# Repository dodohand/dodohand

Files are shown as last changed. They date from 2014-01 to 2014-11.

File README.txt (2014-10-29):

Please see the GeekHack thread on this topic for details.

http://geekhack.org/index.php?topic=41422.0

This project is built around the Teensy 2.0 and is currently using
debug tools from PJRC. Please find the hid_listen tool from PJRC
in order to receive the debug messages from the test DodoHand 
firmware.

At attempt at some coherent notes:

A Brief History

The DataHand keyboard is a design that I have come to rely heavily
upon and do not want to be without. It allows me to type pain-free
for hours at a time, day after day. DataHand Systems has been out
of production for some 10 years now, and their website has even
recently been taken down so I feel left to my own devices to ensure
a long-term future of pain-free typing. This has spawned the DodoHand
project - an attempt to resurrect the now-extinct DataHand.

So you want to create a DodoHand

Current status: The finger switch design is usable. The thumb switch
mechanism designs are complete in their first version, but untested.
A thumb PCB has been designed and ordered. A case has been designed by
Turbinia, but has never been built. There are provisions in hardware
for supporting an EasyPoint or another joystick but these have not
been implemented in software.

Note:

At this point, only the finger switches are tested in any way, and
the rest of the document mainly refers to that portion of the project.

The first step is to get all the parts headed your way. There is 
a BOM.ods (Bill of Materials) in the documentation folder which 
contains a list of the parts needed. That should be your guide.

- Electronics:

There are part numbers and links to Digikey which should make
it easier to get the electronics order placed. 

- 3D-printed parts:

In the 3D_models directory the files plf.scad and show_prf.scad 
should be opened with a recent version of OpenSCAD, compiled, and 
exported as .STL files. These can then be uploaded to Shapeways 
and printed in the "Black, Strong and Flexible" material. Please 
note that there are some fairly tight tolerances and that the 
design requires a bit of flexibility in the printed models in 
order to retain the magnets and center button clips, so don't 
try to print them in an inflexible, or fragile material, or one
with less fidelity than the SLS Nylon "Black, Strong and Flexible".

- PCB:

In the sch_and_pcb folder open up kicad_fingers.brd with a recent
build of KiCAD (I have been working with a build from sources
downloaded in November, 2013) and plot the Gerber files. Verify 
that the drill file matches up with the other files using gerbview
or another Gerber file viewer, then send to a suitable PCB fab
operation like OSH Park, pcbwing, etc. Note that OSH Park will
silently drop overlapping holes so the double-sided TRRS connector
footprint will not be manufactured exactly correctly, but is very
usable anyhow.

Note that you're likely going to need to edit the KiCAD library 
settings in order to point KiCAD at the appropriate library files
in the component_lib directory.

- Metal "clips" which serve as a magnetic attractor

These you'll need to fabricate on your own until/unless I (or you!) 
can find a shop to make them. There is a drawing: tooling/clip_bending_jig.dxf
which I used to create a bending jig. LibreCAD was used to create 
this drawing (turn various layers on/off to help see what's going on).
I substituted 1mm pins for all positions since that is what I was 
able to find from McMaster-Carr, and have been satisfied with the 
results. I used 7075 aluminum IIRC for the body of the jig. Be 
certain to order several drill bits of these small sizes - they're 
very fragile. Also, find a drill press or mill - you aren't likely 
to be successful trying to drill these holes by hand. I think that
0.045"x0.015" strips of mild steel will generate about the right 
force. Some experimentation will likely be needed to get that perfect.
This material can be sourced as a roll of 0.015" shim stock. Please be 
careful when releasing the coiled shim-stock from the strap that
holds it. It will jump out and try to cut your face off if you give
it half a chance to do so.

I am working towards getting a manufacturer lined up for the metal
clips. The first step is a clear mechanical drawing and I hope that
tooling/clip_1_mech.dxf fits that description.

Assembly

The only challenging part of assembly is fitting the 3D-printed parts
together. The Shapeways process has varied enough that some batches
fall right together without much work while others require quite a 
bit of time with a hobby knife, pick, and pin vise. These tools are
needed to re-open the passages for the infrared LED and phototransistor
leads, remove partially sintered material that was not cleaned away
by shapeways, and trim away excess material when their process is 
running on the extra-material end of the spectrum. You are likely
to spend between 2 and 15 minutes on each finger, depending upon 
your luck with Shapeways. Be thorough with the pick in removing
partially sintered material, or each time you insert a part, it
won't go well and you'll end up picking out another little batch
of dust to clear up the void that should have been there.

You should consider ordering a solder-paste stencil for each side
of the PCB. I did the 160 0-Ohm jumpers by-hand, meting out little
dabs of paste onto each pad. That went fine, but I would really
have liked to be able to just squeege across and get on to dropping
those little buggers onto their homes. If you do this, let me know
how it goes!

Don't be afraid of SMD soldering if you haven't done it before.
Particularly with a hot-air wand, it is magically easy. Just a dab
of paste on each pad, drop the part into position, warm it up, and 
when the solder flows the part is pulled into the right spot by
surface tension in the solder. It is just so cool!

Tools used for Assembly:

Here is the list of tools that I recall using so-far in this process:

- a file for cleaning up the little tabs left on the edge of the PCB
  which inevitably get placed right in front of the TRRS connector 
  which is the one spot that they cannot be tolerated.
- no-clean flux
- no-clean wire solder (leaded)
- no-clean solder paste (leaded) (in a syringe)
- no-clean de-soldering braid
- temperature controlled iron - small chisel tip
- hot-air re-work wand
- flush-cut lead snips
- various curved and straight tweezers
- bench shear for cutting metal clips
- dial calipers for measuring and setting metal clip dimensions
- combination square for controlling cuts on bench shear
- diagonal cutters for trimming metal clips to length.
- digital multimeter for testing solder joints
- dental pick
- hobby knife
- Mill for accurately placing holes in bending jig
- tiny drill bits for holes for 1mm pins in bending jig
- pin vise and assorted pin vise drill bits for opening IR lead passages

Software Tools used in project:
- OpenSCAD (build from recent sources) [3D models of switch mechanicals]
- KiCAD (build from recent sources - November, 2013 or later) [schematic, PCB]
- LibreCAD (version 1.0.1) [2D mechanical drawings]
- LibreOffice [Bill of Materials]
- Blender [case design, .stl file validation]
- Inkscape [documentation, logo]
- avr-gcc [compiling software for ATMega32U4 micro]
- GNU make [controlling build process]
- teensy_loader_cli [flashing ATMega32U4 through USB via teensy bootloader]
- simavr (optional) [extreme AVR debugging]
- git [distributed version control]

Programming the keyboard

Yeah, about that... I don't have the actual keyboard firmware written
quite yet. src/led_test.c scans the matrix of the right-hand side of
the keyboard via I2C and recognizes switch presses, and also scans the
left-hand side, but that is as far as I have currently taken it. Soon...

In any case, the Teensy 2.0 comes with a nice bootloader, and the
tactile switch SW1 is hooked to the teensy reset switch which starts
the bootloader. If you get the paths set correctly in Makefile for 
your system, and type make test_prog, the source will build and then
wait to recognize the Teensy bootloader - just press that reset at
that time and away you go.

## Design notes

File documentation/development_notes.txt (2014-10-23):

A place to capture some notes on development steps, strategies, etc.

1) How to verify that the 3D model matches the PCB layout?

So far, the best approach I've used is no take the drill file output
of the PCB design tool and translate it into a bunch of cylinders
in the 3D model. I imported the drill file into OpenOffice Calc,
converted inches to mm, copied the resulting data into Emacs along
with a column that I created for drill diameters. I then created 
an emacs keyboard macro to create something like this for each drill
of interest (only the mounting holes, component leads:

translate([-24.89454,    9.23036, 0]) 
  cylinder(center=true, $fn=gfn, h=100, r= 0.762/2.0);

and add the whole set to the 3D model.

When this matches the 3D model, you can be certain that the PCB
will properly line up with the holes in the switch parts.

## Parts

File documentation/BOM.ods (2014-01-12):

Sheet: Bill of Materials
 |  |  |  |  |  |  |  |  |  |  |  |  |  | mm | mm | mm | inch
Part ID | Description | Supplier | Supplier PN | Manufacturer | Manufacturer PN | Price Each | Quantity | extended | Notes | More Notes | Even More Notes | Added notes | package | l | w | terminal | lead diameter
1 | U2 5v decoupling Cap | Digikey | 445-14795-1-ND (http://www.digikey.com/product-detail/en/C3216X7R1C475K085AB/445-14795-1-ND/3956461) | TDK | C3216X7R1C475K085AB (http://www.digikey.com/product-detail/en/C3216X7R1C475K085AB/445-14795-1-ND/3956461) | $0.28 | 1 | $0.28 |  |  |  |  | 1206 | 3.2 | 1.6 | 0.2
2 | U2 3.3v output cap | Digikey | 445-14795-1-ND (http://www.digikey.com/product-detail/en/C3216X7R1C475K085AB/445-14795-1-ND/3956461) | TDK | C3216X7R1C475K085AB (http://www.digikey.com/product-detail/en/C3216X7R1C475K085AB/445-14795-1-ND/3956461) | $0.28 | 1 | $0.28 |  |  |  |  | 1206 | 3.2 | 1.6 | 0.2
3 | Standard 0.1u decoupling cap | Digikey | 1276-2856-1-ND (http://www.digikey.com/product-detail/en/CL31F104ZBCNNNC/1276-2856-1-ND/3890942) | Samsung | CL31F104ZBCNNNC (http://www.digikey.com/product-detail/en/CL31F104ZBCNNNC/1276-2856-1-ND/3890942) | $0.14 | 3 | $0.42 |  |  |  |  | 1206 | 3.2 | 1.6
4 | 3mm blue LED | Digikey | 365-1201-ND (http://www.digikey.com/product-detail/en/OVLLB8C7/365-1201-ND/827137) | TT Elec / Optek | OVLLB8C7 (http://www.digikey.com/product-detail/en/OVLLB8C7/365-1201-ND/827137) | $0.32 | 2 | $0.64 | 5mm 300mcd @ 20mA / 3.4v | 1.3333333333 | 910 | 900 |  |  |  |  | 0.029
5 | 3mm green LED | Digikey | 365-1202-ND (http://www.digikey.com/product-detail/en/OVLLG8C7/365-1202-ND/827138) | TT Elec / Optek | OVLLG8C7 (http://www.digikey.com/product-detail/en/OVLLG8C7/365-1202-ND/827138) | $0.35 | 2 | $0.70 | 5mm 670mcd @ 20mA / 3.4v | 0.5970149254 | 2112.5 | 2.1k |  |  |  |  | 0.029
6 | 3mm yellow LED | Digikey | 365-1204-ND (http://www.digikey.com/product-detail/en/OVLLY8C7/365-1204-ND/827140) | TT Elec / Optek | OVLLY8C7 (http://www.digikey.com/product-detail/en/OVLLY8C7/365-1204-ND/827140) | $0.19 | 2 | $0.38 | 5mm 650mcd @ 20mA / 2.2v | 0.6153846154 | 3997.5 | 4k |  |  |  |  | 0.029
7 | 3mm red LED | Digikey | 365-1203-ND (http://www.digikey.com/product-detail/en/OVLLR8C7/365-1203-ND/827139) | TT Elec / Optek | OVLLR8C7 (http://www.digikey.com/product-detail/en/OVLLR8C7/365-1203-ND/827139) | $0.19 | 2 | $0.38 | 5mm 570mcd @ 20mA / 2.2v | 0.701754386 | 3497.5 | 3.5k |  |  |  |  | 0.029
8 | 8 position 0.100 pth header | Digikey | 609-3530-ND (http://www.digikey.com/product-detail/en/75869-132LF/609-3530-ND/1524248) | FCI | 75869-132LF (http://www.digikey.com/product-detail/en/75869-132LF/609-3530-ND/1524248) | $0.80 | 5 | $4.00
9 | TRRS Connector | Digikey | CP-43514-ND (http://www.digikey.com/product-detail/en/SJ-43514/CP-43514-ND/368146) | CUI Inc | SJ-43514 (http://www.digikey.com/product-detail/en/SJ-43514/CP-43514-ND/368146) | $1.31 | 2 | $2.62
10 | test point | Digikey | 1040K-ND (http://www.digikey.com/product-detail/en/1040/1040K-ND/315157) | Keystone Electronics | 1040 (http://www.digikey.com/product-detail/en/1040/1040K-ND/315157) | $0.18 | 22 | $3.96
11 | PNP transistor | Digikey | KSA1298YMTFCT-ND (http://www.digikey.com/product-detail/en/KSA1298YMTF/KSA1298YMTFCT-ND/3504462) | Fairchild | KSA1298YMTF (http://www.digikey.com/product-detail/en/KSA1298YMTF/KSA1298YMTFCT-ND/3504462) | $0.22 | 1 | $0.22
12 | U3 pullup resistor | Digikey | P200KFCT-ND (http://www.digikey.com/product-detail/en/ERJ-8ENF2003V/P200KFCT-ND/89947) | Panasonic | ERJ-8ENF2003V (http://www.digikey.com/product-detail/en/ERJ-8ENF2003V/P200KFCT-ND/89947) | $0.10 | 1 | $0.10 |  |  |  |  | 1206 | 3.2 | 1.6
13 | I2C pullup resistor | Digikey | P2.20KFCT-ND (http://www.digikey.com/product-detail/en/ERJ-8ENF2201V/P2.20KFCT-ND/1746562) | Panasonic | ERJ-8ENF2201V (http://www.digikey.com/product-detail/en/ERJ-8ENF2201V/P2.20KFCT-ND/1746562) | $0.10 | 4 | $0.40 |  |  |  |  | 1206 | 3.2 | 1.6
14 | Row Resistor | Digikey | P470FCT-ND (http://www.digikey.com/product-detail/en/ERJ-8ENF4700V/P470FCT-ND/1746601) | Panasonic | ERJ-8ENF4700V (http://www.digikey.com/product-detail/en/ERJ-8ENF4700V/P470FCT-ND/1746601) | $0.10 | 4 | $0.40 |  |  |  |  | 1206 | 3.2 | 1.6
15 | column resistor | Digikey | P2.49KFCT-ND (http://www.digikey.com/product-detail/en/ERJ-8ENF2491V/P2.49KFCT-ND/89732) | Panasonic | ERJ-8ENF2491V (http://www.digikey.com/product-detail/en/ERJ-8ENF2491V/P2.49KFCT-ND/89732) | $0.10 | 8 | $0.80 |  |  |  |  | 1206 | 3.2 | 1.6
16 | Blue LED bias resistor | Digikey | P910FCT-ND (http://www.digikey.com/product-detail/en/ERJ-8ENF9100V/P910FCT-ND/1746631) | Panasonic | ERJ-8ENF9100V (http://www.digikey.com/product-detail/en/ERJ-8ENF9100V/P910FCT-ND/1746631) | $0.10 | 2 | $0.20 | 900 Ohms ish |  |  |  | 1206 | 3.2 | 1.6
17 | Green LED bias resistor | Digikey | P2.10KFCT-ND (http://www.digikey.com/product-detail/en/ERJ-8ENF2101V/P2.10KFCT-ND/89717) | Panasonic | ERJ-8ENF2101V (http://www.digikey.com/product-detail/en/ERJ-8ENF2101V/P2.10KFCT-ND/89717) | $0.10 | 2 | $0.20 | 2.1k ish |  |  |  | 1206 | 3.2 | 1.6
18 | Yellow LED bias resistor | Digikey | P4.02KFCT-ND (http://www.digikey.com/product-detail/en/ERJ-8ENF4021V/P4.02KFCT-ND/89767) | Panasonic | ERJ-8ENF4021V (http://www.digikey.com/product-detail/en/ERJ-8ENF4021V/P4.02KFCT-ND/89767) | $0.10 | 2 | $0.20 | 4k |  |  |  | 1206 | 3.2 | 1.6
19 | Red LED bias resistor | Digikey | P3.48KFCT-ND (http://www.digikey.com/product-detail/en/ERJ-8ENF3481V/P3.48KFCT-ND/89751) | Panasonic | ERJ-8ENF3481V (http://www.digikey.com/product-detail/en/ERJ-8ENF3481V/P3.48KFCT-ND/89751) | $0.10 | 2 | $0.20 | 3.5k |  |  |  | 1206 | 3.2 | 1.6
20 | EP SW eval resistor | Digikey | P4.99KFCT-ND (http://www.digikey.com/product-detail/en/ERJ-8ENF4991V/P4.99KFCT-ND/89788) | Panasonic | ERJ-8ENF4991V (http://www.digikey.com/product-detail/en/ERJ-8ENF4991V/P4.99KFCT-ND/89788) | $0.10 | 2 | $0.20 |  |  |  |  | 1206 | 3.2 | 1.6
21 | U4 pullup resistor | Digikey | P10.0KFCT-ND (http://www.digikey.com/product-detail/en/ERJ-8ENF1002V/P10.0KFCT-ND/89822) | Panasonic | ERJ-8ENF1002V (http://www.digikey.com/product-detail/en/ERJ-8ENF1002V/P10.0KFCT-ND/89822) | $0.10 | 1 | $0.10 |  |  |  |  | 1206 | 3.2 | 1.6
22 | reset switch | Digikey | CKN9120-ND (http://www.digikey.com/product-detail/en/PTS645VH58-2%20LFS/CKN9120-ND/1146783) | C&K Components | PTS645VH58-2 LFS | $0.24 | 1 | $0.24
23 | Teensy | pjrc | TEENSY_PINS | pjrc | TEENSY_PINS | $19.00 | 1 | $19.00
24 | 3.3v linear regulator | Digikey | AP7313-33SAG-7DICT-ND (http://www.digikey.com/product-detail/en/AP7313-33SAG-7/AP7313-33SAG-7DICT-ND/2270840) | Diodes, Inc | AP7313-33SAG-7 (http://www.digikey.com/product-detail/en/AP7313-33SAG-7/AP7313-33SAG-7DICT-ND/2270840) | $0.46 | 1 | $0.46
25 | I2C level shifter | Digikey | 568-4215-1-ND (http://www.digikey.com/product-detail/en/PCA9306D,118/568-4215-1-ND/1638362) | NXP | PCA9306 | $0.78 | 1 | $0.78
26 | I2C I/O expander | Digikey | PCA9655EDWR2GOSCT-ND (http://www.digikey.com/product-detail/en/PCA9655EDWR2G/PCA9655EDWR2GOSCT-ND/2683436) | ON Semi | PCA9655EDWR2G (http://www.digikey.com/product-detail/en/PCA9655EDWR2G/PCA9655EDWR2GOSCT-ND/2683436) | $1.43 | 1 | $1.43
27 | IRLED | Digikey | 160-1063-ND (http://www.digikey.com/product-detail/en/LTE-302/160-1063-ND/153264) | Lite-On | LTE-302 | $0.35 | 40 | $14.12
28 | IRPhotoTrans | Digikey | 1080-1163-ND (http://www.digikey.com/product-detail/en/PT908-7B-F/1080-1163-ND/2675654) | Everlight | PT908-7B-F | $0.33 | 40 | $13.08
38 | 0603 0-Ohm jumper | Digikey | 1276-3510-1-ND (http://www.digikey.com/product-detail/en/RC1608J000CS/1276-3510-1-ND/3903613) | Samsung | RC1608J000CS (http://www.digikey.com/product-detail/en/RC1608J000CS/1276-3510-1-ND/3903613) | $0.0027 | 160 | $0.4320 | Jumpers for connecting IR component leads to switch matrix.
34 | TRRS cable | MyCableMart | FS-4CT-01-MM | MyCableMart | FS-4CT-01-MM | $1.40 | 1 | $1.40
ribbon cable | 8-position 0.050 in spacing | Digikey | MD08R-5-ND (http://www.digikey.com/product-detail/en/HF365%2F08SF/MD08R-5-ND/2416331) | 3M | HF365/08SF (http://www.digikey.com/product-detail/en/HF365%2F08SF/MD08R-5-ND/2416331) | $3.96 | 1 | 1 | 5 feet – for connecting thumbs and easypoint, remote LEDs
35 | USB Cable | MyCableMart | MO-5448 | MyCableMart | MO-5448 | $2.93 | 1 | $2.93
ribbon connector | 8-position | Digikey | 609-3568-ND (http://www.digikey.com/product-detail/en/71600-008LF/609-3568-ND/1523262) | FCI | 71600-008LF (http://www.digikey.com/product-detail/en/71600-008LF/609-3568-ND/1523262) | $0.94 | 5 | $4.70 | for connecting thumbs and easypoint, remote LEDs
 |  |  |  |  |  |  |  | subtotal
 |  |  |  |  |  |  |  | $76.25
29 | left hand 3D parts | Shapeways | Black Strong & Flexible | Shapeways |  | $44.42 | 1 | $44.42
30 | right hand 3D parts | Shapeways | Black Strong & Flexible | Shapeways |  | $44.42 | 1 | $44.42
 |  |  |  |  |  |  |  | 0
31 | PCB (3 of them) | OSHPark |  | OSHPark |  | $77.30 | 1 | $77.30
 |  |  |  |  |  |  |  | 0
32 | center button metal clips | Custom | 0.015” x 0.050” steel |  |  | $1.00 | 8 | $8.00 | Note that $1.00 is a complete fiction
33 | N/E/S/W metal clips | Custom | 0.015” x 0.040” steel |  |  | $1.00 | 32 | $32.00 | I have no idea what a shop would charge to fab these parts.
36 | Magnets, Center switches, 1/4x1/8x1/32”, 10-pack | K&J magnetics | http://www.kjmagnetics.com/proddetail.asp?prod=B4201 | K&J magnetics | http://www.kjmagnetics.com/proddetail.asp?prod=B4201 | 1.1 | 1 | 1.1
37 | Magnets, N/E/S/W switches, 1/8x1/8x1/16” | K&J magnetics | http://www.kjmagnetics.com/proddetail.asp?prod=B221 | K&J magnetics | http://www.kjmagnetics.com/proddetail.asp?prod=B221 | 0.14 | 32 | 4.48
39 | M3 standoffs |  |  |  |  |  |  |  | The mounting holes are sized for M3 screws.
40 | M3 screws |  |  |  |  |  |  |  | The mounting holes are sized for M3 screws.
 |  |  |  |  |  |  |  | total
 |  |  |  |  |  |  |  | $287.97

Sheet: Schematic Export
 |  |  |  | EasyPoint Right Hand Part Counts
ref | value | description | footprint | LH Quantity | RH Quantity | Total Quantity | Part ID
C1 | 4.7uF | U2 5v decoupling Cap (4.7uF) |  | 0 | 1 | 1 | 1
C2 | 4.7uF | U2 3.3v output cap (4.7uF) |  | 0 | 1 | 1 | 2
C3 | 0.1uF | Standard 0.1u decoupling cap |  | 0 | 1 | 1 | 3
C4 | 0.1uF | Standard 0.1u decoupling cap |  | 0 | 1 | 1 | 3
C5 | 0.1uF | Standard 0.1u decoupling cap |  | 0 | 1 | 1 | 3
D10 | LED | 3mm blue LED |  | 1 | 1 | 2 | 4
D11 | LED | 3mm green LED |  | 1 | 1 | 2 | 5
D12 | LED | 3mm yellow LED |  | 1 | 1 | 2 | 6
D13 | LED | 3mm red LED |  | 1 | 1 | 2 | 7
J1 | EP_BOT | 8 position SMT header |  | 0 | 1 | 1 | 8
J2 | EP_TOP | 8 position SMT header |  | 0 | 0 | 0 | 8
J3 | AUX | 8 position SMT header |  | 0 | 0 | 0 | 8
J4 | AUX | 8 position SMT header |  | 0 | 0 | 0 | 8
J5 | SJ-43514 | TRRS Connector |  | 1 | 1 | 2 | 9
J6 | THM_TOP | 8 position SMT header |  | 1 | 0 | 1 | 8
J7 | THM_BOT | 8 position SMT header |  | 0 | 1 | 1 | 8
J8 | ALTLED | 8 position SMT header |  | 1 | 0 | 1 | 8
J9 | ALTLED | 8 position SMT header |  | 0 | 1 | 1 | 8
P1 | TST | test point |  | 1 | 1 | 2 | 10
P2 | TST | test point |  | 1 | 1 | 2 | 10
P3 | TST | test point |  | 1 | 1 | 2 | 10
P4 | TST | test point |  | 1 | 1 | 2 | 10
P5 | TST | test point |  | 1 | 1 | 2 | 10
P6 | TST | test point |  | 1 | 1 | 2 | 10
P7 | TST | test point |  | 1 | 1 | 2 | 10
P8 | TST | test point |  | 1 | 1 | 2 | 10
P9 | TST | test point |  | 1 | 1 | 2 | 10
P10 | TST | test point |  | 1 | 1 | 2 | 10
P11 | TST | test point |  | 1 | 1 | 2 | 10
P12 | TST | test point |  | 0 | 0 | 0 | 10
P13 | TST | test point |  | 0 | 0 | 0 | 10
Q1 | PNP | PNP transistor |  | 0 | 1 | 1 | 11
R1 | 200k | U3 pullup resistor |  | 0 | 1 | 1 | 12
R2 | 2.2k | I2C pullup resistor |  | 1 | 0 | 1 | 13
R3 | 470 | Row Resistors |  | 1 | 1 | 2 | 14
R4 | 470 | Row Resistors |  | 1 | 1 | 2 | 14
R5 | 2.5k | column resistor |  | 1 | 1 | 2 | 15
R6 | 2.5k | column resistor |  | 1 | 1 | 2 | 15
R7 | 2.5k | column resistor |  | 1 | 1 | 2 | 15
R8 | 2.5k | column resistor |  | 1 | 1 | 2 | 15
R9 | 2.2k | I2C pullup resistor |  | 1 | 0 | 1 | 13
R10 | 910 | LED bias resistor |  | 1 | 1 | 2 | 16
R11 | 2.1k | LED bias resistor |  | 1 | 1 | 2 | 17
R12 | 4k | LED bias resistor |  | 1 | 1 | 2 | 18
R13 | 3.5k | LED bias resistor |  | 1 | 1 | 2 | 19
R14 | 5k | EP SW eval resistor |  | 0 | 1 | 1 | 20
R15 | 2.2k | EP I2C pullup |  | 0 | 1 | 1 | 13
R16 | 2.2k | EP I2C pullup |  | 0 | 1 | 1 | 13
R17 | 5k | EP SW eval resistor |  | 0 | 1 | 1 | 20
R18 | 10k | U4 pullup resistor |  | 0 | 1 | 1 | 21
SW1 | SPST | reset switch |  | 1 | 0 | 1 | 22
U1 | TEENSY2P0 | Teensy |  | 1 | 0 | 1 | 23
U2 | LIN_REG | 3.3v linear regulator |  | 0 | 1 | 1 | 24
U3 | PCA9306 | I2C level shifter |  | 0 | 1 | 1 | 25
U4 | PCA9655E | I2C I/O expander |  | 0 | 1 | 1 | 26
 |  | IRLED |  | 20 | 20 | 40 | 27
 |  | IRPhotoTrans |  | 20 | 20 | 40 | 28

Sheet: Pivot Table_Schematic Export_1
Filter
Part ID
1 | 2 | 3 | 4 | 5 | 6 | 7 | 8 | 9 | 10 | 11 | 12 | 13 | 14 | 15 | 16 | 17 | 18 | 19 | 20 | 21 | 22 | 23 | 24 | 25 | 26 | 27 | 28 | (empty) | Total Result
1 | 1 | 3 | 2 | 2 | 2 | 2 | 5 | 2 | 22 | 1 | 1 | 4 | 4 | 8 | 2 | 2 | 2 | 2 | 2 | 1 | 1 | 1 | 1 | 1 | 1 | 40 | 40 |  | 156
 |  |  |  |  |  |  |  |  |  |  |  |  |  |  |  |  |  |  |  |  |  |  |  |  |  |  |  |  |  | #NAME?

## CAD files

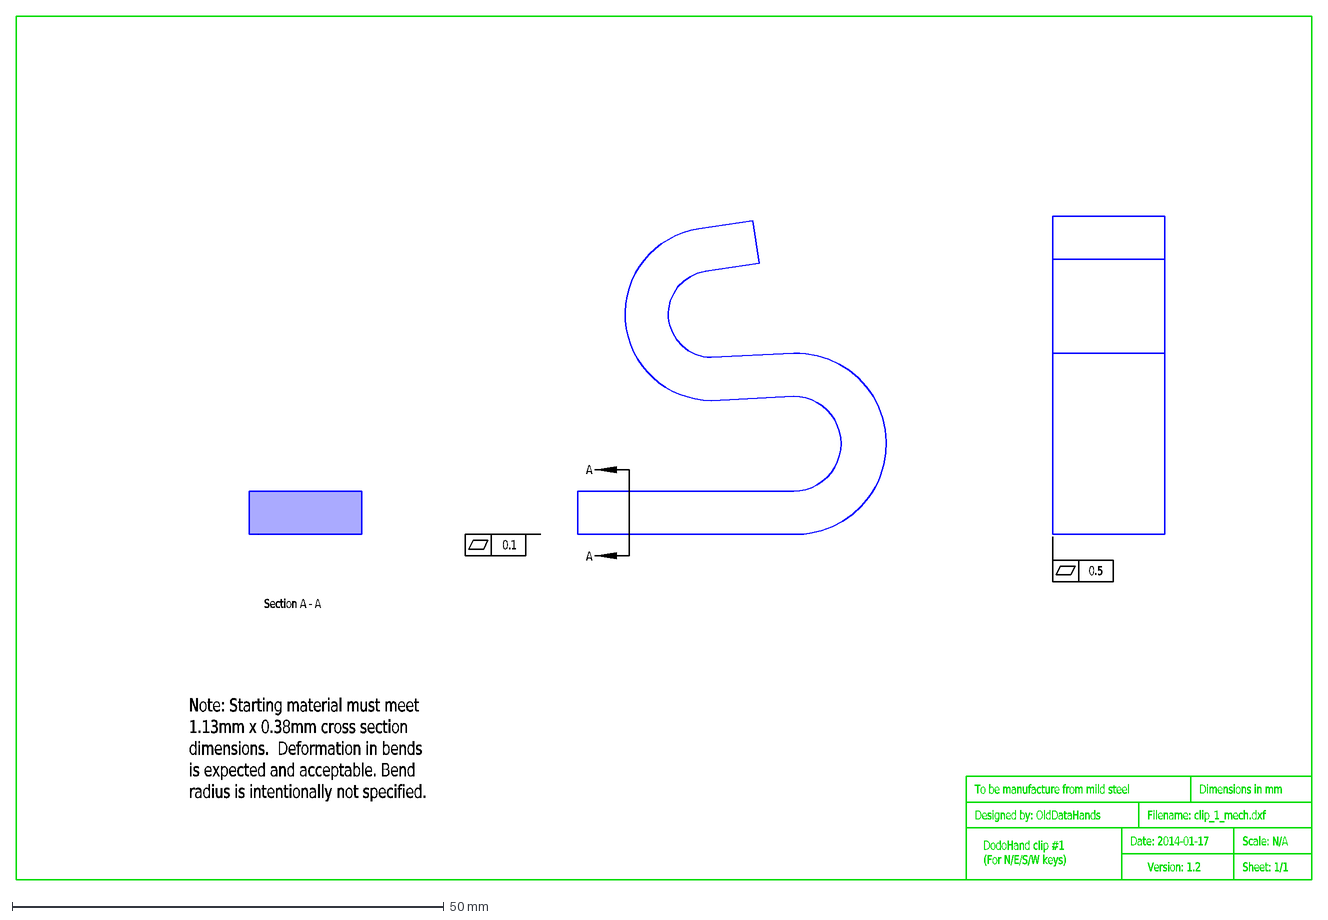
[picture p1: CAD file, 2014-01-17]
tooling/clip_1_mech.dxf
0.1
Section A - A
0.5
A
Sheet: 1/1
Scale: N/A
Date: 2014-01-17
Version: 1.2
DodoHand clip #1 (For N/E/S/W keys)
Filename: clip_1_mech.dxf
Designed by: OldDataHands
To be manufacture from mild steel
Dimensions in mm
Note: Starting material must meet 1.13mm x 0.38mm cross section dimensions. Deformation in bends is expected and acceptable. Bend radius is intentionally not sp

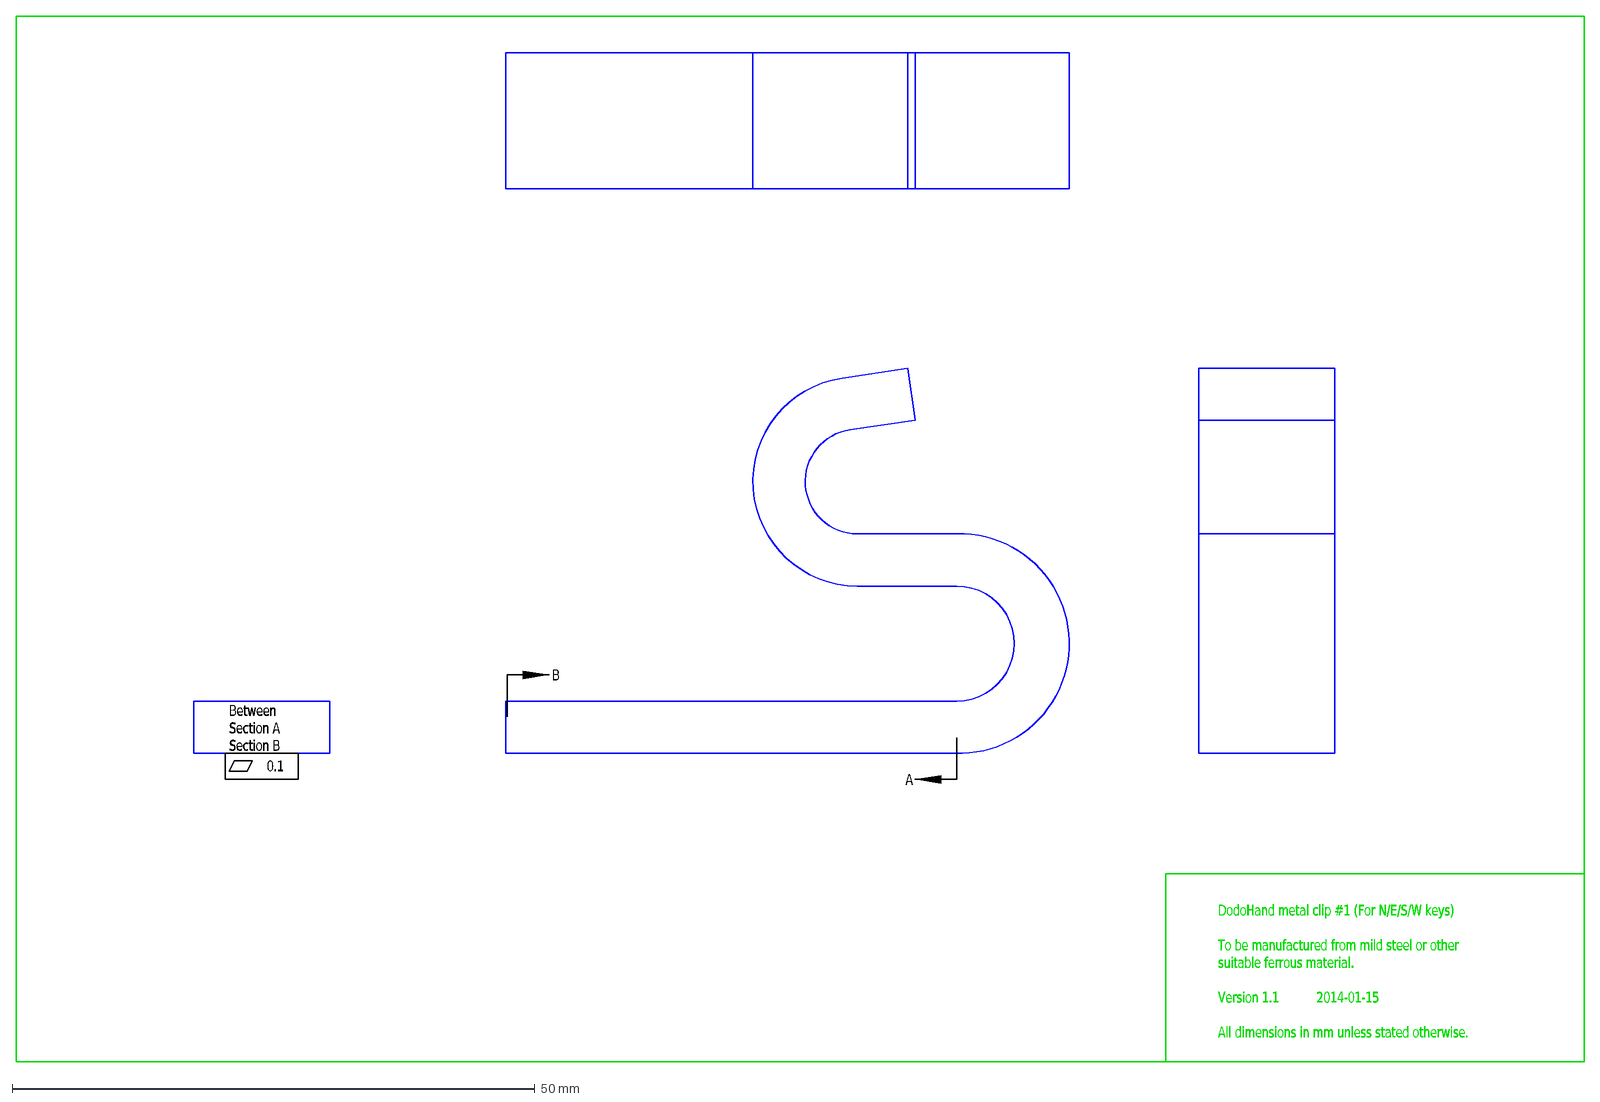
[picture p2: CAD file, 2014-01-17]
tooling/clip_mechanical.dxf
A
0.1
B
Between Section A Section B
DodoHand metal clip #1 (For N/E/S/W keys) To be manufactured from mild steel or other suitable ferrous material. Version 1.1 2014-01-15 All dimensions in mm unl

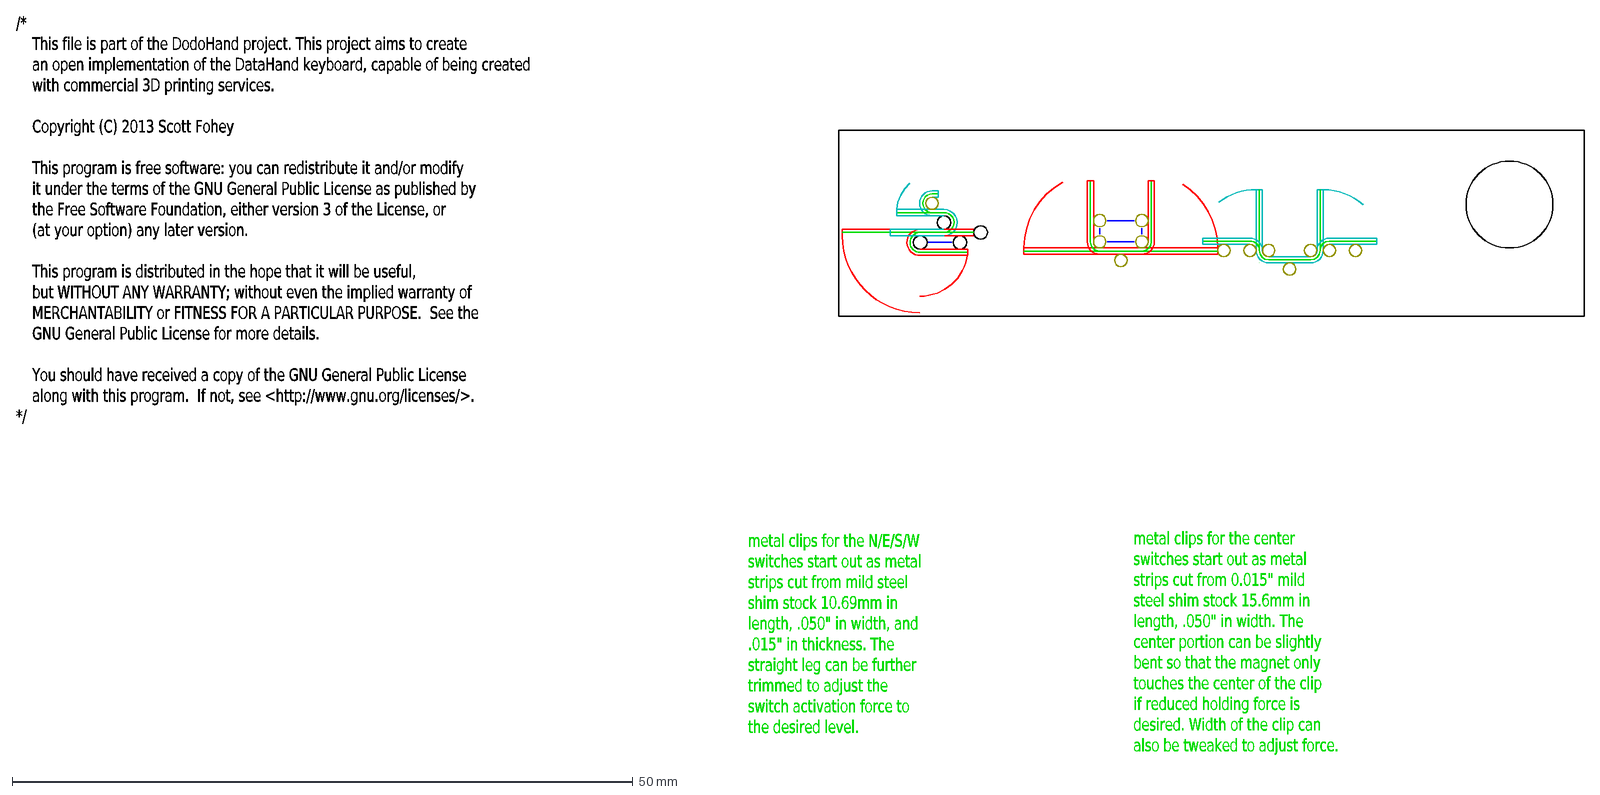
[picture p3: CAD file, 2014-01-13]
tooling/clip_bending_jig.dxf
/* This file is part of the DodoHand project. This project aims to create an open implementation of the DataHand keyboard, capable of being created with commerc
metal clips for the N/E/S/W switches start out as metal strips cut from mild steel shim stock 10.69mm in length, .050" in width, and .015" in thickness. The str
metal clips for the center switches start out as metal strips cut from 0.015" mild steel shim stock 15.6mm in length, .050" in width. The center portion can be

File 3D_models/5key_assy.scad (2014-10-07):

/*
    This file is part of the DodoHand project. This project aims to create 
    an open implementation of the DataHand keyboard, capable of being created
    with commercial 3D printing services.

    Copyright (C) 2013 Scott Fohey

    This program is free software: you can redistribute it and/or modify
    it under the terms of the GNU General Public License as published by
    the Free Software Foundation, either version 3 of the License, or
    (at your option) any later version.

    This program is distributed in the hope that it will be useful,
    but WITHOUT ANY WARRANTY; without even the implied warranty of
    MERCHANTABILITY or FITNESS FOR A PARTICULAR PURPOSE.  See the
    GNU General Public License for more details.

    You should have received a copy of the GNU General Public License
    along with this program.  If not, see <http://www.gnu.org/licenses/>.
*/

// this is the 5-key assembly scad file.

use <lever.scad>;
use <carrier.scad>;
use <LiteOn_P_100_E302.scad>;

// Nom_LiteOn_P_100_E302(-10, 0, 0);

include <dimensions.scad>;

echo("width of magnet showing is:", mag_w-2*lip_w);
echo("height of magnet is:", mag_h);

module key_assy(x, y, z, ang, t, ll, sk, sc, sm, pr, fs) {
  // a is angle to rotate about vertical axis
  // t parameter is 1 for big key, 0 for small key
  // ll parameter means make it a lower lever base.
  // sk = show key
  // sm = show magnet
  // pr = pinkie riser
  // fs = make it with a "frontstop" (opposite of ll base)
  
  translate([x, y, z]) {
    rotate(a=ang, v=[0,0,1]) {
      carrier(0, 0, 0, ll, sc, pr, fs);

      if(1 == sk) {
        if(0 == t) {
          small_key(wl_x, wl_y, wl_z, sm);
        }
        if(1 == t) {
          big_key(wl_x, wl_y, wl_z, sm);
        }
      } // if(1 == sk)
    }
  }
}

module cbutton(x, y, z) {
  translate([x, y, z]) {
    union() {

      translate([cb_x, cb_y, cb_z]) {
        intersection () {
          difference() {
            cylinder(h=cb_h, r=cb_r, $fn=gfn);
            translate([0,0,cbsdr_z]) sphere(r = cbsd_r, $fn=gfn);
          }
          translate([0,0,-7.5]) sphere(r=cbsd_r, $fn=gfn);
        }
      }

      // make the stem of the center pushbutton
      translate([stem_x, stem_y, stem_z]) {
        difference() {
          // starting volume of stem
          union() {
            cube([stem_w, stem_d, stem_h+csg_tol]);
            // spheres for stem retention
            translate([0, stem_d/2, stem_d/4]) 
              scale(v=[min_detail+min_wall,stem_d/4,stem_d/4]) 
                sphere(r=1, $fn=gfn);
            translate([stem_w, stem_d/2, stem_d/4]) 
              scale(v=[min_detail+min_wall,stem_d/4,stem_d/4]) 
                sphere(r=1, $fn=gfn);
            // spines on edges to reduce friction
            translate([-ss_d, stem_d/2-ss_w/2, 0]) 
              cube([ss_d, ss_w, stem_h+csg_tol]);
            translate([stem_w, stem_d/2-ss_w/2, 0]) 
              cube([ss_d, ss_w, stem_h+csg_tol]);
          }
          // split the bottom of stem for room to snap into position
          translate([stem_w/2 - min_sep, -csg_tol/2, -csg_tol])
            cube([2*min_sep, stem_d+csg_tol, 6.5*min_sep]);
          // round the top of the split to reduce concentration of stress
          translate([stem_w/2, 0, 6.5*min_sep-csg_tol]) rotate(a=-90, v=[1,0,0]) 
            cylinder(r=min_sep, h=stem_d, $fn=gfn);
          // recess both sides of the stem to reduce friction
          translate([2*min_detail, stem_d-min_detail, -min_detail])
            cube([stem_w-4*min_detail, min_detail+csg_tol, stem_h]);
          translate([2*min_detail, -csg_tol, -min_detail])
            cube([stem_w-4*min_detail, min_detail+csg_tol, stem_h]);

          difference() {
            // starting volume of "round the bottom of the stem" box
            translate([-csg_tol-min_sep, -csg_tol, -csg_tol]) 
              cube([stem_w + 2*min_sep + 2*csg_tol, 
                    stem_d + 2*csg_tol, 
                    stem_d/2 + csg_tol]);
            // subtract out a cylinder to get a matching cyl on stem bottom
            translate([-2*csg_tol-min_sep, stem_d/2, stem_d/2]) 
              rotate(a=90, v=[0,1,0]) 
                cylinder(h=sbrc_w, r=(stem_d/2), $fn=gfn);
          } // difference for rounded bottom

        } // difference for stem subtractions

      } // translate stem    

    } // union
  } // translate([x,y,z])
}

module clip2_retainer(x, y, z) {
  // add retainer for center pushbutton clip
  translate([x, y, z])
    intersection() {
      rotate(a=clip2_ret_yrot, v=[0,1,0]) {
        rotate(a=-clip2_ret_zrot, v=[0,0,1]) {
          translate([-1 * (clip2_ret_w_ex + csg_tol), 0, 0]) {
            cube([clip2_ret_w + clip2_ret_w_ex, clip2_ret_d, clip2_ret_h]);
          }
        }
      }

      // trim off the end(s) to make certain that it doesn't end up
      // violating the minimum separations.
      translate([-csg_utol, -2.5 * clip2_ret_d, -2.5*clip2_ret_h ])
        cube([clip2_ret_w + 2 * csg_utol, 5 * clip2_ret_d, 5*clip2_ret_h]);

  } // intersection
}

module chock(x, y, z, ck) {
  // ck = chock: 0=not shown, 1=shown, 2=ghost
  // add in chock which keeps clip2 in position
  if(1 == ck) {
    translate([x, y, z]) {
      cube([clip2_chock_w, clip2_chock_d, clip2_chock_h]);
    }
  }
  if(2 == ck) {
    translate([x, y, z]) {
      %cube([clip2_chock_w, clip2_chock_d, clip2_chock_h]);
    }
  }
}

module chock_tree(x, y, z, tr) {
  // tr = tree for printing: 1=top, 2=bottom
  // add in chock which keeps clip2 in position
  if(1 == tr) {
    translate([x, y, z]) {
      union() {
        cube([clip2_chock_w, clip2_chock_d, clip2_chock_h]);
        cube([min_wire, min_wire, 2.0 * clip2_chock_h]);
      }
    }
  }
  if(2 == tr) {
    translate([x, y, z]) {
      union() {
        cube([clip2_chock_w, clip2_chock_d, clip2_chock_h]);
        translate([0, 0, -clip2_chock_h]) 
          cube([min_wire, min_wire, 2.0 * clip2_chock_h]);
      }
    }
  }
}


module carrier_group(x, y, z, sk, sc, sm, sh, pr, ck, sl) {
  // sk = show keys
  // sc = show clips (ferrous targets)
  // sm = show magnet
  // sh = show holes 
  // pr = pinkie riser
  // ck = chock: 0=not shown, 1=shown, 2=ghost
  // sl = show lower lever 0=not shown, 1=shown

  translate([x, y, z]) {
    union () {

      key_assy(0, 0, 0, 0, 1, 1, sk, sc, sm, pr, 0);
    
      key_assy(floor_w + sw_d - min_wall, sw_d - min_wall, 0, 90, 0, 0, 
               sk, sc, sm, pr, 0);
    
      key_assy(floor_w, 2*sw_d - 2*min_wall + floor_w, 0, 180, 0, 0, 
               sk, sc, sm, pr, 1);
    
      key_assy(-sw_d+min_wall, floor_w + sw_d - min_wall, 0, 270, 0, 0, 
               sk, sc, sm, pr, 0);
    
      // add in support for center PB IR eyes
      // add in volume to hold center pushbutton IRLEDs
      difference() {
        translate([cpilh_x, cpilh_y, cpilh_z-pr]) 
          cube([cpilh_w, cpilh_d, cpilh_h+pr]);

        Max_LiteOn_P_100_E302(cpil_x, cpil_y, cpil_z-csg_utol, -15*min_wall);
        // this doesn't exactly meet the sides of the sphere, 
        // but seems close enough.
        translate([cpilhs_x, cpilhs_y, cpilhs_z-csg_utol-pr]) 
          cylinder(r=irle_m_r, h=irle_z+csg_utol+pr, $fn=gfn);

        if ( 0.0 != pr ) {
          translate([cpil_x, cpil_y, cpil_z-csg_utol-pr]) {
            rotate(a=90, v=[0,0,1]) {
              color("Salmon") {
                cube([irlb_m_w, irlb_m_d, pr+csg_tol]);
              }
            }
          }
        }
      }

      // add in support/guide for center pushbutton stem 
      // long support walls
      translate([cbsw_x-csg_tol/2, cbsw_y, cbsw_z]) 
        cube([cbsw_w+csg_tol, cbsw_d, cbsw_h]);
      translate([cbsw_x-csg_tol/2, 
                 cbsw2_y, 
                 cbsw_z]) 
        cube([cbsw_w+csg_tol, cbsw_d, cbsw_h]);
      // short support walls / retaining function for stem
      translate([cbssw_x, cbssw_y-csg_tol/2, cbssw_z]) 
        cube([cbssw_w, cbssw_d+csg_tol, cbssw_h]);
      translate([cbssw_x + cbssw_w + stem_w + 2*ss_d, 
                 cbssw_y-csg_tol/2, 
                 cbssw_z]) 
        cube([cbssw_w, cbssw_d+csg_tol, cbssw_h]);
      // end walls to tie into surrounding carrier structure
      translate([cbsswc_x, cbsswc_y, cbsswc_z])
        cube([cbsswc_w, cbsswc_d, cbsswc_h]);
      translate([cbsswc_x+cbsw_w+min_wall, cbsswc_y, cbsswc_z])
        cube([cbsswc_w, cbsswc_d, cbsswc_h]);


      translate([floor_w, 0, 0]) {
        mirror(v=[1,0,0]) {
          difference() {
            translate([cpilh_x, cpilh_y, cpilh_z-pr]) 
              cube([cpilh_w, cpilh_d, cpilh_h+pr]);
    
            Max_LiteOn_P_100_E302(cpil_x, cpil_y, cpil_z-csg_utol, -15*min_wall);
            // this doesn't exactly meet the sides of the sphere, 
            // but seems close enough.
            translate([cpilhs_x, cpilhs_y, cpilhs_z-csg_utol-pr]) 
              cylinder(r=irle_m_r, h=irle_z+csg_utol+pr, $fn=gfn);
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

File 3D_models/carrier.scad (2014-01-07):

/*
    This file is part of the DodoHand project. This project aims to create 
    an open implementation of the DataHand keyboard, capable of being created
    with commercial 3D printing services.

    Copyright (C) 2013 Scott Fohey

    This program is free software: you can redistribute it and/or modify
    it under the terms of the GNU General Public License as published by
    the Free Software Foundation, either version 3 of the License, or
    (at your option) any later version.

    This program is distributed in the hope that it will be useful,
    but WITHOUT ANY WARRANTY; without even the implied warranty of
    MERCHANTABILITY or FITNESS FOR A PARTICULAR PURPOSE.  See the
    GNU General Public License for more details.

    You should have received a copy of the GNU General Public License
    along with this program.  If not, see <http://www.gnu.org/licenses/>.
*/

include <dimensions.scad>;

use <LiteOn_P_100_E302.scad>;

// bend_1 goes out from into the X direction and up
module c_r_bend_1(x, y, z) {
  // the piece of a clip which composes the corner-bend,
  // will be used to show the bend instead of a perfect square connection

  translate([x, y, z]) {

    translate([0, 0, clip_bend_h]) rotate(a=-90, v=[1,0,0]) {
    
      intersection() {
    
        difference() {
          // cylinder which has it's outer surface as the outside of the bend
          cylinder(h=clip_w, r=clip_bend_h, $fn=gfn);
          
          // subtract cylinder to leave inner radius of bend -- leaves a toroid
          translate([0, 0, -csg_tol/2]) 
            cylinder(h=clip_w+csg_tol, r=clip_inn_r, $fn=gfn);
      
        } // end difference
    
        cube([clip_bend_h, clip_bend_h, clip_w]);
    
      } // intersection
    } // translate/rotate
  } // translate([x,y,z])
}

// bend_2 goes out into the x direction and down.
module c_r_bend_2(x, y, z) {
  // the piece of a clip which composes the corner-bend,
  // will be used to show the bend instead of a perfect square connection

  translate([x, y, z]) {

    translate([0, clip_w, -clip_inn_r]) rotate(a=90, v=[1,0,0]) {
    
      intersection() {
    
        difference() {
          // cylinder which has it's outer surface as the outside of the bend
          cylinder(h=clip_w, r=clip_bend_h, $fn=gfn);
          
          // subtract cylinder to leave inner radius of bend -- leaves a toroid
          translate([0, 0, -csg_tol/2]) 
            cylinder(h=clip_w+csg_tol, r=clip_inn_r, $fn=gfn);
      
        } // end difference
    
        cube([clip_bend_h, clip_bend_h, clip_w]);
    
      } // intersection
    } // translate/rotate
  } // translate([x,y,z])
}

// bend_3 goes up into the z direction and then curves into X.
module c_r_bend_3(x, y, z) {
  // the piece of a clip which composes the corner-bend,
  // will be used to show the bend instead of a perfect square connection

  translate([x, y, z]) {

    translate([clip_mat_t, 0, 0]) rotate(a=-90, v=[0,1,0]) 
    translate([0, clip_w, -clip_inn_r]) rotate(a=90, v=[1,0,0]) {
    
      intersection() {
    
        difference() {
          // cylinder which has it's outer surface as the outside of the bend
          cylinder(h=clip_w, r=clip_bend_h, $fn=gfn);
          
          // subtract cylinder to leave inner radius of bend -- leaves a toroid
          translate([0, 0, -csg_tol/2]) 
            cylinder(h=clip_w+csg_tol, r=clip_inn_r, $fn=gfn);
      
        } // end difference
    
        cube([clip_bend_h, clip_bend_h, clip_w]);
    
      } // intersection
    } // translate/rotate
  } // translate([x,y,z])
}

// bend_4 goes down in the z direction and then curves into X.
module c_r_bend_4(x, y, z) {
  // the piece of a clip which composes the corner-bend,
  // will be used to show the bend instead of a perfect square connection

  translate([x, y, z]) {
    translate([0, clip_w, 0]) rotate(a=180, v=[1,0,0])
    translate([clip_mat_t, 0, 0]) rotate(a=-90, v=[0,1,0]) 
    translate([0, clip_w, -clip_inn_r]) rotate(a=90, v=[1,0,0]) {
    
      intersection() {
    
        difference() {
          // cylinder which has it's outer surface as the outside of the bend
          cylinder(h=clip_w, r=clip_bend_h, $fn=gfn);
          
          // subtract cylinder to leave inner radius of bend -- leaves a toroid
          translate([0, 0, -csg_tol/2]) 
            cylinder(h=clip_w+csg_tol, r=clip_inn_r, $fn=gfn);
      
        } // end difference
    
        cube([clip_bend_h, clip_bend_h, clip_w]);
    
      } // intersection
    } // translate/rotate
  } // translate([x,y,z])
}

module clip(x, y, z) {
  translate([x, y, z]) {
    
    color("Silver") union() {

// Clip #1 ( for N,S,E,W buttons )
//
//       <-- A -->
//      ----------
//     D|<-B>
//      -----
//           |E
//         --
//         C

      translate([0, 0, -clip_A]) cube([clip_w, clip_mat_t, clip_A -clip_inn_r]);
      rotate(a=90, v=[0,0,1]) c_r_bend_3(0, -clip_w, -clip_inn_r);
      translate([0, clip_bend_h, 0]) 
        cube([clip_w, clip_D-clip_bend_h-clip_bend_h, clip_mat_t]);
      rotate(a=90, v=[0,0,1]) c_r_bend_2(clip_D-clip_bend_h, -clip_w, 0);
      translate([0, clip_D-clip_mat_t, -clip_B+clip_inn_r ])
        cube([clip_w, clip_mat_t, clip_B-(2*clip_inn_r)]);
      rotate(a=90, v=[0,0,1]) 
        c_r_bend_4(clip_D-clip_mat_t,-clip_w,-clip_B-clip_mat_t+clip_bend_h);
      translate([0, clip_D-clip_mat_t+clip_bend_h, -clip_B-clip_mat_t]) 
        cube([clip_w, clip_E-clip_bend_h-clip_bend_h, clip_mat_t]);
      rotate(a=90, v=[0,0,1]) 
        c_r_bend_1(clip_D+clip_E-clip_mat_t-clip_bend_h, -clip_w, -clip_B-clip_mat_t);
      translate([0, clip_D+clip_E-2*clip_mat_t, -clip_B+clip_inn_r])
        cube([clip_w, clip_mat_t, clip_C-clip_inn_r]);
    } // union
  } // translate
} // module clip

module clip2(x, y, z) {
  translate([x, y, z]) {
    color("Silver") union() {

// Clip #2 (for center button)
//
//   C             C
// ------       ------
//     B|       |B
//      ---------
//          A

      translate([ clip2_C1_x, 0, clip2_B]) {
        cube([clip2_C-clip_bend_h, clip2_w, clip_mat_t]);
        c_r_bend_2(clip2_C-clip_bend_h, 0, 0);
      }
      translate([ clip2_B1_x, 0, clip_bend_h]) {
        cube([clip_mat_t, clip2_w, clip2_B-clip_inn_r-clip_bend_h]);
        c_r_bend_4(0, 0, 0);
      }
      translate([ clip2_A_x, 0, 0]) {
        cube([clip2_A-(2*clip_bend_h), clip2_w, clip_mat_t]);
        c_r_bend_1(clip2_A-(2*clip_bend_h), 0, 0);
      }
      translate([ clip2_B2_x, 0, clip_bend_h]) {
        cube([clip_mat_t, clip2_w, clip2_B-clip_bend_h-clip_inn_r]);
        c_r_bend_3(0, 0, clip2_B-clip_inn_r-clip_bend_h);
      }
      translate([ clip2_C2_x, 0, clip2_B]) 
        cube([clip2_C-clip_bend_h, clip2_w, clip_mat_t]);

    } // union
  } // translate
} // module clip2

module sidewall(pr) {
  // pr = pinkie riser
  union() {
    difference() {
      union() {
        // make sidewall 
        translate([sw_x, sw_y, sw_z]) cube([sw_w, sw_d, sw_h]);
        // make cap that blocks light from hitting sensor
        translate([swcap_x, swcap_y, swcap_z])
          cube([swcap_w, swcap_d, swcap_h]);
      }
      // subtract sidewall lock void
      translate([swlv_x, swlv_y-csg_tol, swlv_z]) 
        cube([swlv_w+csg_tol, swlv_d+csg_tol, swlv_h]);
      // subtract the sidewall lock void relief
      translate([swlvr_x, swlvr_y, swlvr_z]) 
        rotate(a=swlvr_a, v=[1,0,0]) 
          cube([swlvr_w+csg_tol, swlvr_d, swlvr_h]);
      // subtract max-tolerance IR device
      Max_LiteOn_P_100_E302(irl_x, irl_y, irl_z, -min_wall-csg_utol-pr);
      // subtract to make lever out of back of sidewall so eye can snap in
      translate([swlc_x-(csg_tol/2), swlc_y, swlc_z]) 
        cube([swlc_w+irltol+csg_tol, swlc_d, swlc_h]);
      translate([swlc_x-(csg_tol/2), swlc_y + irlb_w + irltol -swlc_d, swlc_z]) 
        cube([swlc_w+irltol+csg_tol, swlc_d, swlc_h]);
      // subtract cylinder to make opening/shield for eye
      translate([-csg_tol+min_wall+irlb_m_d, min_wall+irle_m_x, irl_z+irle_m_z])
        rotate(a=90, v=[0,1,0]) 
          cylinder(h=sw_eye_wall_w+2*csg_tol, r=irle_m_r, $fn=gfn);
    }
    // add in retaining bump to ensure that a nominal IR device is held firm
    translate([min_wall, irl_y + irle_x, irl_z + irle_z]) 
    sphere(r=irltol*1.5, $fn=gfn);

  }
}
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

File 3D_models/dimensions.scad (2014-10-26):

/*
    This file is part of the DodoHand project. This project aims to create 
    an open implementation of the DataHand keyboard, capable of being created
    with commercial 3D printing services.

    Copyright (C) 2013, 2014 Scott Fohey

    This program is free software: you can redistribute it and/or modify
    it under the terms of the GNU General Public License as published by
    the Free Software Foundation, either version 3 of the License, or
    (at your option) any later version.

    This program is distributed in the hope that it will be useful,
    but WITHOUT ANY WARRANTY; without even the implied warranty of
    MERCHANTABILITY or FITNESS FOR A PARTICULAR PURPOSE.  See the
    GNU General Public License for more details.

    You should have received a copy of the GNU General Public License
    along with this program.  If not, see <http://www.gnu.org/licenses/>.
*/

// This file defines dimensions for all aspects of all models.

show_mag = 0;
// angle to show lever rotation
show_lr_angle = 0;

// global face number set here
gfn=87; // 87 is the max that fit in the shapeways 64MB size limit.
//gfn=12;
//gfn=50;

// units are in mm

// used to convert inches to mm
in2mm = 25.4;

/* originally used - seems a bit tight.
 * // properties of shapeways sls nylon
 * min_wall = 0.7;
 * min_wire = 1.0;
 * min_sep  = 0.5;
 * proc_tol = 0.15; // plus 0.15% of overall length
 * min_detail = 0.2;
 * ptp_clearance = 0.2;
*/

// properties of shapeways sls nylon
// after first prototype - desire to back away from process limits
min_wall = 0.7;
proc_min_wire = 1.0;
min_wire = proc_min_wire + 0.2;
proc_min_sep = 0.5;
min_sep  = proc_min_sep + 0.2;
proc_tol = 0.2; // plus 0.15% of overall length
min_detail = 0.3;
ptp_clearance = 0.3;

csg_tol = 0.1; // fudge a volume larger than needed in case plane is left 
csg_utol = 0.01; // fudge a volume just a bit larger than needed......
// after a difference operation.

//*****************************************************************************
//*****************************************************************************
// start of dimensioning and positioning of lever components
//

// dimensions of the magnet to be used for the N/E/S/W (side) buttons
// K&J Magnetics B221 magnet
smag_w = in2mm * 1/8;
smag_h = in2mm * 1/8;
smag_d = in2mm * 1/16;
smag_hole_tol = 0.2;

// dimensions of the magnet to be used for the center pushbutton
// K&J Magnetics B4201 magnet
mag_w = in2mm * 1/8;
mag_h = in2mm * 1/4;
mag_d = in2mm * 1/32;
mag_hole_tol = 0.2;

lip_w = 0.5 + mag_hole_tol/2;     // lip size which retains magnet
lev_d = 1;       // depth of material in lever
slev_d = lev_d + mag_d;
lev_h = 12;      // height of lever (below key, not including pivot radius)
slev_h = 2 * smag_h;
pivot_w = min_detail; // width of extension of lower pivot beyond side of lever
bump_r = min_detail;  // width of anti-friction bumps on side of lever

keyring_r = 8.5;
key_inner_r = keyring_r - 1.5;
key_outer_r = key_inner_r + 3;
key_back_ang = -8.0;
lgkey_back_ang = -5.0;

// radius of lower lever pivot
pivot_r = lev_d/2;

// outer dimension width of the pocket which holds the magnet
// magnets barely fit so added mag_hole_tol to boost the pocket size.
pocket_w = mag_w + (min_wall * 2) + mag_hole_tol;

// dimensions of flexible clip which captures magnet
mag_clip_w = min_wire;
// dimensions of the hole in which the flexible clip sits.
levhole_w = 2*min_sep + mag_clip_w;

// min lever width is two side wires + center clip + 2 gaps
min_lev_w = 2*min_wire + levhole_w;

// lever width (excluding bumps, key, and locking bars)
lev_w = (pocket_w < min_lev_w) ? min_lev_w : pocket_w;

// finish position of magnet now that lever width is known
mag_pos_x = lev_w/2 - mag_w/2;
mag_pos_y = lev_d;
// put mag at top of lever, leaving room for bridge and keeper bump.
mag_pos_z = lev_h - min_wire - min_wire - mag_h;
smag_pos_z = mag_pos_z + (mag_h - smag_h);
smag_pos_x = mag_pos_x;
smag_pos_y = lev_d-smag_d/2;

// make volume to subtract from lever - clip will go in here
clip_h = (2 * min_wire) + mag_h;
sclip_h = (2 * min_wire) + smag_h;
levhole_h = min_sep + clip_h - 2*min_wire;
slevhole_h = min_sep + sclip_h - min_wire;
levhole_pos_z = lev_h - clip_h - min_wire - min_sep;
slevhole_pos_z = lev_h - sclip_h - min_wire - min_sep;
levhole_pos_x = lev_w/2 - levhole_w/2;

// locate the sidewalls which support the lips
sidewall_pos_x = lev_w/2 - pocket_w/2;

// locate the lips which retain the magnet
lip_pox_x = sidewall_pos_x + min_wall;
lip_pos_y = lev_d + mag_d;
lip_pos_z = mag_pos_z;
slip_pos_z = lip_pos_z + (mag_h - smag_h);

// locate the clip which retains the magnet
clip_pos_x = lev_w/2 - mag_clip_w/2;
clip_pos_z = lev_h - clip_h - min_wire;
sclip_pos_z = lev_h - sclip_h - min_wire;
stop_pos_z = lev_h - min_wire - min_wire + proc_tol;

// locate the keeper bump which hold magnet at bottom
keeper_pos_z = mag_pos_z - min_wire;
skeeper_pos_z = smag_pos_z - min_wire;

// locate the pivot on which the lever moves
pivot_r = lev_d/2;
pivot_oal = lev_w + 2*pivot_w;
pivot_x_pos = lev_w/2 - pivot_oal/2;
pivot_y_pos = pivot_r;
pivot_z_pos = 0;

// locate the bumps on the side of the lever which reduce friction with carrier
bump_h = min_wall;
bump_pos_x = lev_w;
bump_pos_y = lip_pos_y;
bump_pos_z = mag_pos_z + mag_h/2;
sbump_pos_z = mag_pos_z + mag_h/2 + bump_r;
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

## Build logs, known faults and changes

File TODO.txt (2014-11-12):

/*
    This file is part of the DodoHand project. This project aims to create 
    an open implementation of the DataHand keyboard, capable of being created
    with commercial 3D printing services.

    Copyright (C) 2013 Scott Fohey

    This program is free software: you can redistribute it and/or modify
    it under the terms of the GNU General Public License as published by
    the Free Software Foundation, either version 3 of the License, or
    (at your option) any later version.

    This program is distributed in the hope that it will be useful,
    but WITHOUT ANY WARRANTY; without even the implied warranty of
    MERCHANTABILITY or FITNESS FOR A PARTICULAR PURPOSE.  See the
    GNU General Public License for more details.

    You should have received a copy of the GNU General Public License
    along with this program.  If not, see <http://www.gnu.org/licenses/>.
*/

The TODO list

Circuit/PCB (Fingers):

The Easypoint switch is on Col5, but there is no pull-down on the
finger PCB for Col5, as the intention was to put the Col5 pull-down
on the Thumb PCB, along with the Col4 pulldown. This may have been
an error, as now the Easypoint switch can't be evaluated without
a kludge of soldering on a resistor somehow, at least until the
thumb switches are in the mix. Consider changing this.

regack created a better solder bridge layout. This needs to be 
incorporated into the footprint for the finger 5-switch. It has
already been incorporated into the thumb PCB.

The drills for the test points are not quite large enough for the chosen
testpoints. Make the drill hits a few mil larger so that the testpoints fit
better into the plated holes.

DONE:
PCA9306 circuit needs to be corrected. VREF2 (5.0v) needs to be connected
through the 200kOhms resistor, not directly.

DONE:
SW1 footprint - correct soldermask on mechanical/mounting holes, add padring
  to aid in soldering of the switch for mechanical stability.

TRRS footprint has silkscreen only on one layer. Add to bottom layer.

1206 component footprints have no silkscreen for outline of part. Either
  reduce the soldermask size or move silkscreen away from pads so that it
  actually exists on the real board.

DONE:
PCA9306 text needs to be move to the PCA9306, rather than on the PCA9655e.

DONE:
Add label for PCA9655e.

Add outline of keystop/shroud on the bottom layer.

Add a guide in silkscreen to the solder-bridges, like done on the reversible
  finger 5-switch bridges.

Improve the silkscreen for the status LEDs, on both top and bottom.

Investigate convention for square v. round pads for LEDs... Ergodox diodes
  have long leg through square pad, dodohand currently reverse...

May be possible to tighten-up the pad <-> soldermask spacing so that less
of the traces are exposed coming off of the ASICs...

misc:

Update the clip bending jig drawing to reflect the new, shorter length
of one of the magnet-facing legs of the N/E/S/W clips.

3D_models:

Finger button issues:

DONE:
Orientation of parts when printed affect results.
Arrange Printable Left Fingers SCAD model (3D_models/plf.scad) such that all of 
the keys and the lower levers are arranged in the same orientation. Perhaps pick
the orientation that is currently used for the larger N/big key, as that 
resulted in a part which fit into the carrier without modification.

DONE:
The lower lever seems too narrow @ the retention pins. Side-to-Side slop is too
great. Try orienting same as big key for next print.

DONE:
The printing orientation of the N key vs. the E/S/W keys caused the magnet-
carrying portion of the key levers to be drastically different. Keep this in
mind when selecting the final printing orientation.

DONE:
Add New center clip retention block to plf so that they get printed.

DONE:
Extend clip support wall down to bottom of 5-key carrier to prevent lowlev
from getting out of place if pins get sloppy.

DONE:
The lower-lever retaining pins entry ramp ends in a point which doesn't
print well. Fix this by adding some material to make the point into a chamfer.

DONE:
When printed in their current orientation, the E/S/W keys do not fit into the 
carrier. The top of the retention pins are too high. Assembly required trimming.
Verify that the model is correct. -- DONE -- model was correct --

DONE:
The LowLev cannot be properly inserted into carrier. There is an interference 
between the pivot at the end of the lever and the clip support wall of the N (or
is it S?) key. 

DONE:
The center button stem is way too sloppy. It allows significant and undesirable
motion of the button. The supporting walls should be made into a longer guide to
restrict motion, and the gap for 3D-printing tolerances should be reduced in 
order to achieve a less-sloppy assembly. 
*** at the moment, the short support walls (which work with the retention bumps 
on the stem) have been lengthened slightly (lower edge lowered), and the gap has
been removed between the stem and the support walls. Upper edge of support
structure has been raised slightly as well. *** 

DONE:
The center button stem can jam on the corner of the anvil, trapping the key in
the pressed-down state. This should be prevented simply by reducing the slop in
the stem support. Additional measures should be taken to make this even less 
possible. (now anvil overhangs a bit so that there is a much greater margin for
error without jam)

DONE:
The magnets barely fit into the lower lever. (Now sidewalls moved out to
allow more room in anvil area where structure is too stiff to give easily.)

DONE:
The E/S/W keys don't clear the top edge of the carrier when installed.
(tweaked key_p_z slightly to raise keys)

DONE:
The actuation of the center button requires a bit more force than is perfectly
desirable, and is a bit too snappy for my taste. The clip should be moved 
inboard until it is against the center column to increase the leverage that the
stem has upon the magnet. This will make actuation of the button less snappy and
require less force.  Current build has the clips rounded so that less material
is directly against the magnet, which also helps.  Current build has center 
clips out of 0.015" stock.
*** clip2 relocated, lowlev updated accordingly, new retention mechanism 
created which should make assembly easier.

DONE:
The actuation of the N/E/S/W buttons is perhaps not snappy enough - feels a bit
mushy. This could be improved by using K&J Magnetics' B221 magnet (1/8"x1/8"x
1/16") instead of B4201 (1/4"x1/8"x1/32") as the B221 has a higher Surface 
Field, and could be biased to the top of the lever. This could provide a greater
holding force, and a steeper dropoff of pull as the lever is actuated.

DONE:
Now using a phototransistor which is less sensitive to ambient light (Everlight
PT908-7B-F) and has shorter leads than the LTR-301 which was used earlier. There
needs to be an new 3D model created for the PT908-7B-F which reflects the 
shorter, and equal-length leads so that it can be obvious that they are barely
long enough to work with the current pinkie riser.

DONE:
The pocket for the IR opto components was just a little too short. Some of the
pockets required pliers to get the components to snap in. The hight of the 
pocket should be slightly increased. (pocket now irlb_m_h_xtra = 0.1 taller.)

Case:

A model of a case should be developed. Ensure that the two units can be placed
closer together than the original DataHand. Perhaps the outer case and the hand
support will be part of a single model to reduce complexity and cost of 
manufacture. 3D-printed ceramic is a potential solution. mkawa's 3D printer may
also be a useful resource for a case.  laser-cut cardboard (or plywood/bamboo/acrylic/etc) may not be a bad option.

Thumb switch issues:

Thumb side switch keycaps for all side switches are too tall. lower them.

Thumb side switch activation force and return force are too low.
re-design to use the thicker magnet used for the TDDS.

retention clips broke off upon insertion of TRP. Trimming length of retension
pins just a shave each stopped this. Trim retension pins just a bit.
consider re-shaping the retension clips to improve robustness.

TDDS activation force is too high for first stage, too low (at least in 
comparison) for the second stage. might be solved/improved by lengthening the TDDS.

Thumb switches

DONE:
Develop a model for the two-stage thumb switch and keycap.

DONE:
Develop a model for the 4-count normal thumb switch.

DONE:
Develop a model for the upper/inboard thumb switch keycap.

DONE:
Develop a model for the main inboard thumb switch keycap.

DONE:
Develop a model for the distal outboard thumb switch keycap.

DONE:
Develop a model for the proximal outboard thumb switch keycap.

DONE:
Finalize the positions of the thumb switches relative to eachother.

DONE:
Create a two-sided PCB design for the thumb switches.

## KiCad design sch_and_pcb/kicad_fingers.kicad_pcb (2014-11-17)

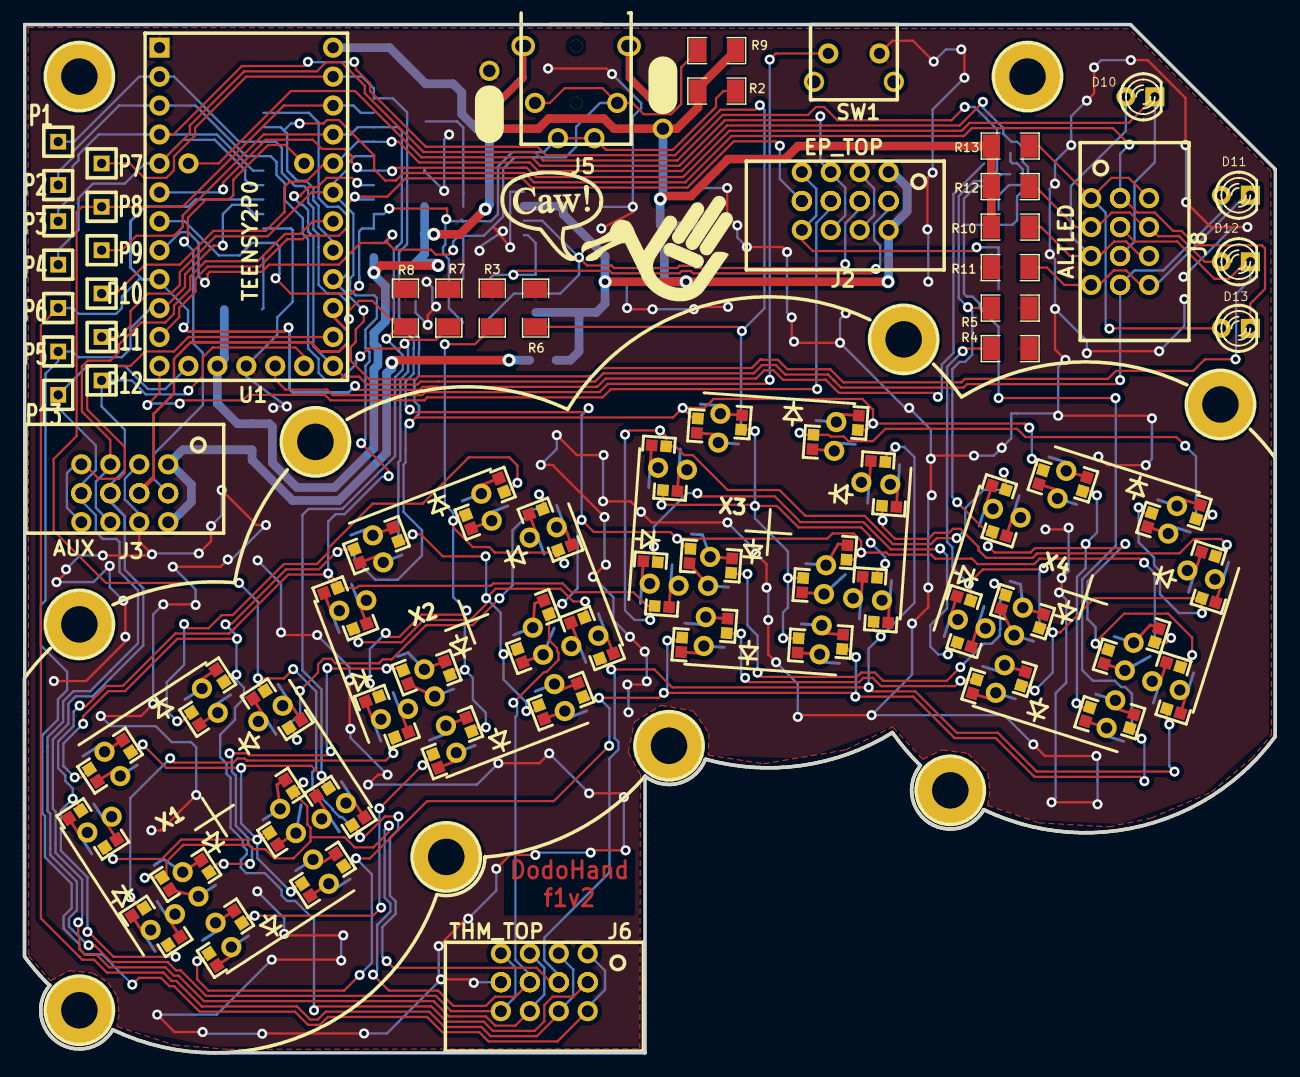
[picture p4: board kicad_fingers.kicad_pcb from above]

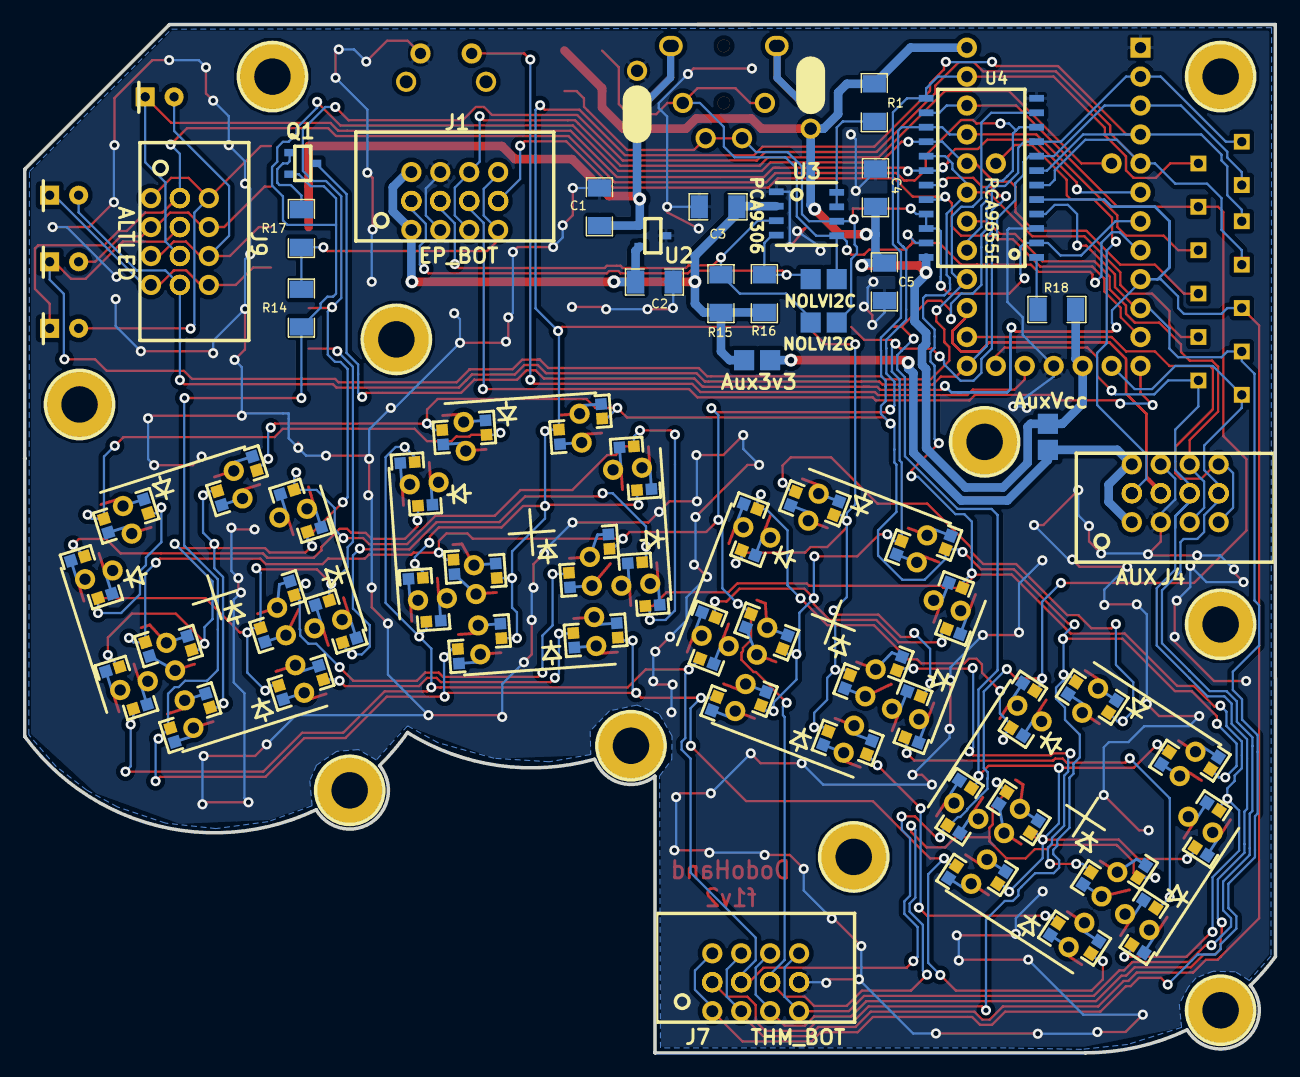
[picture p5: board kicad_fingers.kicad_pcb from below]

Board: 2 copper layers, 109.8 x 90.3 mm, 73 parts (23 on the bottom side), 53 nets.

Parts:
B1: AuxVcc; SOLDER_BR
B2: Aux3v3; SOLDER_BR
B3, B4: NOLVI2C; SOLDER_BR
C1: 4.7; SM1206
C2: 4.7uF; SM1206
C3, C4, C5: 0.1uF; SM1206
D10, D11, D12, D13: LED; LED-3MM-DH
J1: EP_BOT; pth_8_hdr
J2: EP_TOP; pth_8_hdr
J3, J4: AUX; pth_8_hdr
J5: SJ-43514
J6: THM_TOP; pth_8_hdr
J7: THM_BOT; pth_8_hdr
J8, J9: ALTLED; pth_8_hdr
M3_Mounting_Hole, M3_Mounting_Hole#2, M3_Mounting_Hole#3, M3_Mounting_Hole#4, M3_Mounting_Hole#5, M3_Mounting_Hole#6, M3_Mounting_Hole#7, M3_Mounting_Hole#8, M3_Mounting_Hole#9, M3_Mounting_Hole#10: VAL**; M3_Mounting_Hole
P1, P2, P3, P4, P5, P6, P7, P8, P9, P10, P11, P12, P13: TST; SIL-1
Q1: PNP_KSA1298; SOT23
R1: 200k; SM1206
R2, R9, R15, R16: 2.2k; SM1206
R3, R4: 470; SM1206
R5, R6, R7, R8: 2.49k; SM1206
R10, R11, R12, R13: 1k; SM1206
R14, R17: 5k; SM1206
R18: 10k; SM1206
SW1: SPST; PTS645V
U1: TEENSY2P0; TEENSY2p0
U2: LIN_REG; SOT23
U3: PCA9306; SO8
U4: PCA9655E; SOIC24_PCA9655E
X1, X2, X3, X4: RF5S; rf5s

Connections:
+3.3V: B2.1, C2.1, C3.2, J1.2, J2.2, R15.1, R16.1, U2.2, U3.2
/AREF: J3.2, J4.2, U1.AREF
/B4: J3.4, J4.4, U1.B4
/COL0: P1.1, R8.1, U1.B0, U4.9, X1.12, X1.14, X1.16, X1.18, X1.20
/COL1: P2.1, R7.1, U1.B1, U4.8, X2.12, X2.14, X2.16, X2.18, X2.20
/COL2: P3.1, R6.1, U1.B2, U4.7, X3.12, X3.14, X3.16, X3.18, X3.20
/COL3: P4.1, R5.1, U1.B3, U4.6, X4.12, X4.14, X4.16, X4.18, X4.20
/COL4: J6.4, J7.4, P6.1, Q1.3, U1.D2, U4.5
/COL5: J6.2, J7.2, P5.1, U1.D3, U4.4
/D4: J3.6, J4.6, J6.6, J7.6, P12.1, U1.D4
/D5: J3.8, J4.8, J6.8, J7.8, P13.1, U1.D5
/D7: J3.7, J4.7, U1.D7
/EPINT: J1.6, J2.6, U1.E6
/EPRST: J1.7, J2.7, U1.C6, U4.20
/EPSPARE: J1.5, J2.5, U1.C7
/EPSW: J1.8, J2.8, R14.1, R17.1
/F7: J3.5, J4.5, U1.F7
/LED_0: D13.2, J8.1, J9.1, U1.B6, U4.10
/LED_1: D12.2, J8.3, J9.3, U1.B5, U4.11
/LED_2: D10.2, J8.5, J9.5, U1.B7, U4.18
/LED_D6_3: D11.1, J8.7, J9.7, U1.D6, U4.19
/LVSCL: B4.2, J1.3, J2.3, R15.2, U3.3
/LVSDA: B3.2, J1.1, J2.1, R16.2, U3.4
/ROW0: J6.1, J7.1, P7.1, U1.F0, U4.13, X1.1, X1.11, X2.11, X3.1, X3.11, X4.11
/ROW1: J6.3, J7.3, P8.1, U1.F1, U4.14, X1.3, X1.13, X2.13, X3.3, X3.13, X4.13
/ROW2: J6.5, J7.5, P9.1, U1.F4, U4.15, X1.5, X1.15, X2.15, X3.5, X3.15, X4.15
/ROW3: P10.1, Q1.2, R14.2, U1.F5, U4.16, X1.7, X1.17, X2.17, X3.7, X3.17, X4.17
/ROW4: P11.1, U1.F6, U4.17, X1.9, X1.19, X2.19, X3.9, X3.19, X4.19
/SCL: B4.1, J5.3, R2.2, U1.D0, U3.6, U4.2, U4.21, U4.22
/SDA: B3.1, J5.2, R9.2, U1.D1, U3.5, U4.23
/TRST: SW1.1, U1.RST
GND: C1.2, C2.2, C3.1, C4.2, C5.2, J1.4, J2.4, J3.3, J4.3, J5.1, J6.7, J7.7, R3.2, R4.2, R5.2, R6.2, R7.2, R8.2, R11.2, SW1.2, U1.GND, U2.3, U3.1, U4.3, U4.12
unnamed: D10.1, J8.6, J9.6, R10.2
unnamed: D11.2, J8.8, J9.8, R11.1
unnamed: D12.1, J8.4, J9.4, R12.2
unnamed: D13.1, J8.2, J9.2, R13.2
unnamed: Q1.1, R17.2
unnamed: R1.1, U3.7, U3.8
unnamed: R3.1, X2.2, X2.4, X2.6, X2.8, X2.10
unnamed: R4.1, X4.2, X4.4, X4.6, X4.8, X4.10
unnamed: R18.2, U4.1
unnamed: X1.2, X2.1
unnamed: X1.4, X2.3
unnamed: X1.6, X2.5
unnamed: X1.8, X2.7
unnamed: X1.10, X2.9
unnamed: X3.2, X4.1
unnamed: X3.4, X4.3
unnamed: X3.6, X4.5
unnamed: X3.8, X4.7
unnamed: X3.10, X4.9
VCC: B1.1, C1.1, C4.1, C5.1, J5.4, R1.2, R2.1, R9.1, R10.1, R12.1, R13.1, R18.1, U1.Vcc, U2.1, U4.24
VCOM: B1.2, B2.2, J3.1, J4.1

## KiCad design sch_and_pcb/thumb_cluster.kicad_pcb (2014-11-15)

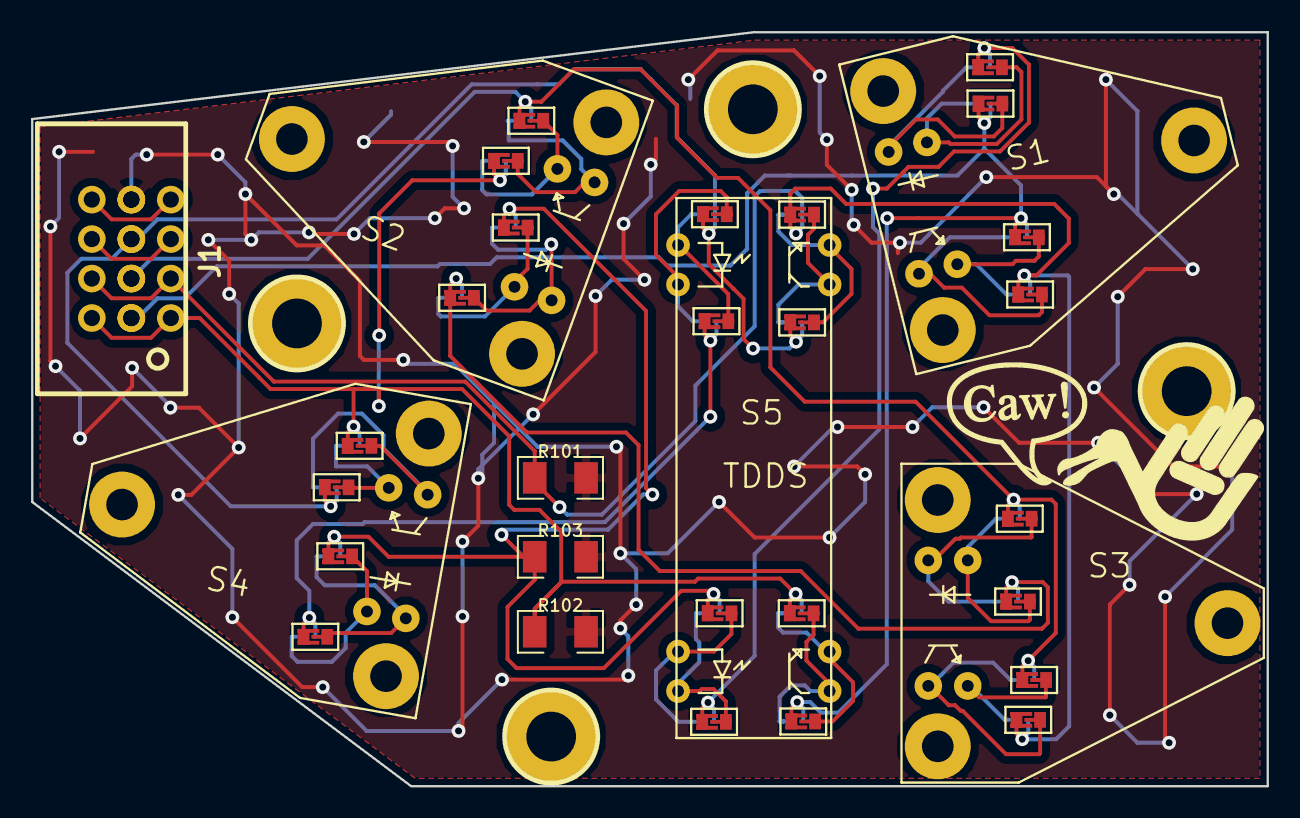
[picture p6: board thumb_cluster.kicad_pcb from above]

Board: 2 copper layers, 79.5 x 48.5 mm, 38 parts (1 on the bottom side), 36 nets.

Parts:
J1, J2: 8PIN_CONN; pth_8_hdr
M3_Mounting_Hole, M3_Mounting_Hole#2, M3_Mounting_Hole#3, M3_Mounting_Hole#4: VAL**; M3_Mounting_Hole
R101, R102: 2.49k; SM1206
R103: 470; SM1206
S1: S1; ThumbSwitch
S2: S2; ThumbSwitch
S3: S3; ThumbSwitch
S4: S4; ThumbSwitch
S5: TDDS
SB1, SB2, SB3, SB4, SB5, SB6, SB7, SB8, SB9, SB10, SB11, SB12, SB13, SB14, SB15, SB16, SB17, SB18, SB19, SB20, SB21, SB22, SB23, SB24: 2XSSB; 2xSideSolderSwitch

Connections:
/COL4: J1.4, J2.4, R101.1, SB13.1, SB14.1, SB15.1
/COL5: J1.2, J2.2, R102.1, SB16.1, SB17.1, SB18.1
/D4: J1.6, J2.6
/D5: J1.8, J2.8
/ROW0: J1.1, J2.1, SB1.1, SB19.1, SB22.1
/ROW1: J1.3, J2.3, SB2.1, SB20.1, SB23.1
/ROW2: J1.5, J2.5, SB3.1, SB21.1, SB24.1
GND: J1.7, J2.7, R101.2, R102.2, R103.2
unnamed: R103.1, SB10.1, SB11.1, SB12.1
unnamed: S1.1, SB1.3, SB7.2
unnamed: S1.2, SB1.2, SB7.3
unnamed: S1.3, SB13.3, SB19.2
unnamed: S1.4, SB13.2, SB19.3
unnamed: S2.1, SB5.3, SB11.2
unnamed: S2.2, SB5.2, SB11.3
unnamed: S2.3, SB17.3, SB23.2
unnamed: S2.4, SB17.2, SB23.3
unnamed: S3.1, SB2.3, SB8.2
unnamed: S3.2, SB2.2, SB8.3
unnamed: S3.3, SB14.3, SB20.2
unnamed: S3.4, SB14.2, SB20.3
unnamed: S4.1, SB6.3, SB12.2
unnamed: S4.2, SB6.2, SB12.3
unnamed: S4.3, SB18.3, SB24.2
unnamed: S4.4, SB18.2, SB24.3
unnamed: S5.1, SB3.3, SB9.2
unnamed: S5.2, SB3.2, SB9.3
unnamed: S5.3, SB4.3, SB10.2
unnamed: S5.4, SB4.2, SB10.3
unnamed: S5.5, SB16.3, SB22.2
unnamed: S5.6, SB16.2, SB22.3
unnamed: S5.7, SB15.3, SB21.2
unnamed: S5.8, SB15.2, SB21.3
unnamed: SB4.1, SB7.1
unnamed: SB5.1, SB8.1
unnamed: SB6.1, SB9.1

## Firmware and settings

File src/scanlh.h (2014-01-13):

/*
    This file is part of the DodoHand project. This project aims to create 
    an open implementation of the DataHand keyboard, capable of being created
    with commercial 3D printing services.

    Copyright (C) 2014 Scott Fohey

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
    You should have received a copy of the GNU General Public License
    along with this program.  If not, see <http://www.gnu.org/licenses/>.
*/
#ifndef __SCANLH_H__
#define __SCANLH_H__

#include "dh_types.h"

#define LH_KB_COLS ( 6u )

/*
 * Row0 = Pin F0
 * Row1 = Pin F1
 * Row2 = Pin F4
 * Row3 = Pin F5
 * Row4 = Pin F6
 *
 * Col0 = Pin B0
 * Col1 = Pin B1
 * Col2 = Pin B2
 * Col3 = Pin B3
 * Col4 = Pin D2
 * Col5 = Pin D3
 *
 */

#define PORTF_ROW_MASK ( 0x73u )
#define PORTF_ROW_0    ( 0x01u )
#define PORTF_ROW_1    ( 0x02u )
#define PORTF_ROW_2    ( 0x10u )
#define PORTF_ROW_3    ( 0x20u )
#define PORTF_ROW_4    ( 0x40u )

#define PORTB_COL0_PIN ( 0x00u )
#define PORTB_COL1_PIN ( 0x01u )
#define PORTB_COL2_PIN ( 0x02u )
#define PORTB_COL3_PIN ( 0x03u )
#define PORTD_COL4_PIN ( 0x02u )
#define PORTD_COL5_PIN ( 0x03u )

#define COL_STAB_T_US ( 300u )

#define KB_ROWS    (5u)

extern bool lh_matrix[KB_ROWS][LH_KB_COLS];

extern void scanlh ( void );




#endif // __SCANLH_H__

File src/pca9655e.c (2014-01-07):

/*
    This file is part of the DodoHand project. This project aims to create 
    an open implementation of the DataHand keyboard, capable of being created
    with commercial 3D printing services.

    Copyright (C) 2013 Scott Fohey

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
    You should have received a copy of the GNU General Public License
    along with this program.  If not, see <http://www.gnu.org/licenses/>.
*/

#include "pca9655e.h"
#include <util/twi.h>


#define PCA9655E_WR_CFG_CMD_CNT ( 6u )
t_dh_twi_cmd pca9655e_wr_cfg_cmds[PCA9655E_WR_CFG_CMD_CNT] = {
  { DH_TWI_CMD_START, 0 },
  { 0, DH_IOE_ADDR | TW_WRITE },           // address the PCA9655E
  { 0, PCA9655E_REG_CMD_CFG0 },            // address config register 0
  { 0, DH_PCA9655E_CR0_DEF },              // write to CR0
  { 0, DH_PCA9655E_CR1_DEF },              // write to CR1
  { DH_TWI_CMD_STOP, 0 } 
};

static t_dh_twi_packet wr_cfg_pkt = { PCA9655E_WR_CFG_CMD_CNT, 
                                      0,
                                      0,
                                      pca9655e_wr_cfg_cmds };

// note that this reads the inputs before writing the outputs so that status 
// can be read before changing outputs invalidates results.
#define PCA9655E_CYC_CMD_CNT ( 13u )
t_dh_twi_cmd pca9655e_cyc_cmds[PCA9655E_CYC_CMD_CNT] = {
  { DH_TWI_CMD_START, 0 },
  { 0, DH_IOE_ADDR | TW_WRITE },           // address the PCA9655E
  { 0, PCA9655E_REG_CMD_IP0 },             // address IP0 register
  { DH_TWI_CMD_START, 0 },
  { 0, DH_IOE_ADDR | TW_READ },            // re-address PCA9655E
  { DH_TWI_CMD_READ | DH_TWI_CMD_ACK, 0 }, // elicit IP0 register contents
  { DH_TWI_CMD_READ, 0 },                  // elicit IP1 register contents
  { DH_TWI_CMD_START, 0 },
  { 0, DH_IOE_ADDR | TW_WRITE },
  { 0, PCA9655E_REG_CMD_OP0 },
  { 0, 0 }, // default to turning off the outputs
  { 0, 0 }, // default to turning off the outputs
  { DH_TWI_CMD_STOP, 0 }
};

static t_dh_twi_packet cyc_pkt = { PCA9655E_CYC_CMD_CNT,
                                   0,
                                   0,
                                   pca9655e_cyc_cmds };


#define PCA9655E_SCANRH_CMD_CNT ( 67u )
/* 
 * Important Note: This approach will work at 100kHz, but may not work 
 * at higher I2C frequencies as the phototransistors need some time to
 * stabilize before being read. Careful evaluation of actual timing
 * will be needed to determine if higher I2C frequencies will drive a
 * need to re-structure the communications to ensure acceptable switch
 * state evaluation timing. Alternately, the intra-packet Stop->Start
 * Timer1A delayed interrupt might be extended to achieve acceptable
 * timing at higher clock speeds...
 */
t_dh_twi_cmd pca9655e_scanrh_cmds[PCA9655E_SCANRH_CMD_CNT] = {
  /* Send init sequence so that keyboard recovers quickly if reattached */
  { DH_TWI_CMD_START, 0 },
  { 0, DH_IOE_ADDR | TW_WRITE },          // address the PCA9655E
  { 0, PCA9655E_REG_CMD_CFG0 },           // address config register 0
  { 0, DH_PCA9655E_CR0_DEF },             // write to CR0
  { 0, DH_PCA9655E_CR1_DEF },             // write to CR1
  { DH_TWI_CMD_STOP, 0 },
  /* start scanning matrix */
  { DH_TWI_CMD_START, 0 },                // send START on I2C - write addr
  { 0, DH_IOE_ADDR | TW_WRITE },          // address the PCA9655E
  { 0, PCA9655E_REG_CMD_OP0 },            // address the OP0 register ( 2 LEDs )
  { 0, 0 }, // idx=9  OP0 outputs ( 2 LEDs ) default to turning off the outputs
  /* Turn ON Row0 */
  { 0, 0 }, // idx=10  OP1 outputs ( Matrix Rows, etc ) default to off
  { DH_TWI_CMD_STOP, 0 },
  { DH_TWI_CMD_START, 0 },                // send START on I2C - write addr
  { 0, DH_IOE_ADDR | TW_WRITE },          // address the PCA9655E
  { 0, PCA9655E_REG_CMD_IP0 },            // address the IP0 register
  { DH_TWI_CMD_START, 0 },                // send Re-Start on I2C - read inputs
  { 0, DH_IOE_ADDR | TW_READ },           // address the PCA9655E
  /* Read state of North Switches */
  { DH_TWI_CMD_READ | DH_TWI_CMD_NAK, 0}, // idx=17 elicit IP0 register contents
  { DH_TWI_CMD_START, 0 },                // send Re-Start - write outputs
  { 0, DH_IOE_ADDR | TW_WRITE },          // address the PCA9655E
  { 0, PCA9655E_REG_CMD_OP1 },            // address the OP0 register ( 2 LEDs )
  /* Turn ON Row1 */
  { 0, 0 }, // idx=21  OP1 outputs ( Matrix Rows, etc ) default to off
  { DH_TWI_CMD_STOP, 0 },
  { DH_TWI_CMD_START, 0 },                // send START on I2C - write addr
  { 0, DH_IOE_ADDR | TW_WRITE },          // address the PCA9655E
  { 0, PCA9655E_REG_CMD_IP0 },            // address the IP0 register
  { DH_TWI_CMD_START, 0 },                // send Re-Start on I2C - read inputs
  { 0, DH_IOE_ADDR | TW_READ },           // address the PCA9655E
  /* Read state of East Switches */
  { DH_TWI_CMD_READ | DH_TWI_CMD_NAK, 0}, // idx=28 elicit IP0 register contents
  { DH_TWI_CMD_START, 0 },                // send Re-Start - write outputs
  { 0, DH_IOE_ADDR | TW_WRITE },          // address the PCA9655E
  { 0, PCA9655E_REG_CMD_OP1 },            // address the OP0 register ( 2 LEDs )
  /* Turn ON Row2 */
  { 0, 0 }, // idx=32  OP1 outputs ( Matrix Rows, etc ) default to off
  { DH_TWI_CMD_STOP, 0 },
  { DH_TWI_CMD_START, 0 },                // send START on I2C - write addr
  { 0, DH_IOE_ADDR | TW_WRITE },          // address the PCA9655E
  { 0, PCA9655E_REG_CMD_IP0 },            // address the IP0 register
  { DH_TWI_CMD_START, 0 },                // send Re-Start on I2C - read inputs
  { 0, DH_IOE_ADDR | TW_READ },           // address the PCA9655E
  /* Read state of Center Switches */
  { DH_TWI_CMD_READ | DH_TWI_CMD_NAK, 0}, // idx=39 elicit IP0 register contents
  { DH_TWI_CMD_START, 0 },                // send Re-Start - write outputs
  { 0, DH_IOE_ADDR | TW_WRITE },          // address the PCA9655E
  { 0, PCA9655E_REG_CMD_OP1 },            // address the OP0 register ( 2 LEDs )
  /* Turn ON Row3 */
  { 0, 0 }, // idx=43 OP1 outputs ( Matrix Rows, etc ) default to off
  { DH_TWI_CMD_STOP, 0 },
  { DH_TWI_CMD_START, 0 },                // send START on I2C - write addr
  { 0, DH_IOE_ADDR | TW_WRITE },          // address the PCA9655E
  { 0, PCA9655E_REG_CMD_IP0 },            // address the IP0 register
  { DH_TWI_CMD_START, 0 },                // send Re-Start on I2C - read inputs
  { 0, DH_IOE_ADDR | TW_READ },           // address the PCA9655E
  /* Read state of South Switches */
  { DH_TWI_CMD_READ | DH_TWI_CMD_NAK, 0}, // idx=50 elicit IP0 register contents
  { DH_TWI_CMD_START, 0 },                // send Re-Start - write outputs
  { 0, DH_IOE_ADDR | TW_WRITE },          // address the PCA9655E
  { 0, PCA9655E_REG_CMD_OP1 },            // address the OP0 register ( 2 LEDs )
  /* Turn ON Row4 */
  { 0, 0 }, // idx=54 OP1 outputs ( Matrix Rows, etc ) default to off
  { DH_TWI_CMD_STOP, 0 },
  { DH_TWI_CMD_START, 0 },                // send START on I2C - write addr
  { 0, DH_IOE_ADDR | TW_WRITE },          // address the PCA9655E
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

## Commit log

2014-01-07 Initial import to github. Scanning of right-hand matrix working well.
    [5key_assy.scad, BOM.ods, LiteOn_P_100_E302.scad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]
2014-01-12 Added jumpers and noted standoffs in BOM. Overview added to README.
    [BOM.ods]
2014-01-13 led_test now also scans the left-hand matrix.
    [clip_bending_jig.dxf]
2014-01-14 first pass at a mechanical drawing for clip no. 1.
    [clip_mechanical.dxf]
2014-01-16 .blend of Case Components
    This is a mock up of the case components.
2014-01-17 prior to redline by an M.E.
    [clip_mechanical.dxf]
2014-01-17 clip_1_mech.dxf ready for quote.
    [clip_1_mech.dxf]
2014-01-17 Added cross-hatch in Section A-A. Tweaked README.
    [clip_1_mech.dxf]
2014-02-13 just starting work on thumb switches.
    [dimensions.scad, show_trp.scad, trp.scad]
2014-02-16 corrections, shoulder added.
    [dimensions.scad, trp.scad]
2014-02-16 winding of polyhedron corrected thanks to Marius Kintel of OpenSCAD.
    [dimensions.scad]
2014-02-16 blade overall structure/shape done. now need to add clip support.
    [dimensions.scad, trp.scad]
2014-02-21 moving towards a final form for thumb switch rotating part.
    [dimensions.scad, show_trp.scad, trp.scad]
2014-02-22 trp now shaped for clip insertion.
    [show_trp.scad, trp.scad]
2014-02-22 thumb rotating part shape v 1.0
    [dimensions.scad, trp.scad]
2014-02-23 started work on frame for 4-per-side thumb switches
    [dimensions.scad, show_trp.scad, tf.scad]
2014-02-23 more work towards thumb frame
    [dimensions.scad, tf.scad]
2014-02-23 now recognizable, significant work left to do on tf.
    [dimensions.scad, show_trp.scad, tf.scad]
2014-02-25 added gussets to support side-loads.
    [dimensions.scad, show_trp.scad, tf.scad]
2014-02-25 filled in area under irled holders for strength.
    [dimensions.scad, tf.scad]
2014-02-26 corners of baseplate removed.
    [dimensions.scad, tf.scad]
2014-02-26 retention clips added.
    [dimensions.scad, show_trp.scad, tf.scad]
2014-03-02 adjusted tf dimensions towards less trp rotation.
    [dimensions.scad, show_trp.scad, tf.scad]
2014-03-08 moved spline and added hole in spline to allow keycap to lock into spline.
    [dimensions.scad, trp.scad]
2014-03-08 keycapbase created - can now create keycaps in Blender for easier organic shape.
    [dimensions.scad, show_trp.scad, tf.scad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]
2014-03-23 starting work on thumb down double-switch.
    [dimensions.scad, show_kcb.scad, show_tdds.scad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]
2014-03-25 further work towards the tdds.
    [dimensions.scad, tdds.scad]
2014-03-30 added magnet holder to one end of bar.
    [dimensions.scad, show_tdds.scad, tdds.scad]
2014-03-31 re-wrote tdds to take advantage of symmetries.
    [dimensions.scad, show_tdds.scad, tdds.scad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]
2014-03-31 tdds switch mechanism functional. KeyCap still to be created and mounting provided.
    [dimensions.scad, tdds.scad]
2014-03-31 added pressure bumps to ensure IRLEDs are held firmly.
    [dimensions.scad, tdds.scad]
2014-09-16 added retention bumps for TDDS keycap.
    [dimensions.scad, tdds.scad, util.scad]
2014-10-02 added tdds lifting travel stop. Also calculation for tdds keycap rotation.
    [dimensions.scad, tdds.scad]
2014-10-04 beginnings of tdds keycap.
    [dimensions.scad, tdds.scad]
2014-10-06 tdds keycap now clearanced for magnets. correctly attached to pivot.
    [tdds.scad]
2014-10-06 shaped the tdds keycap.
    [dimensions.scad, tdds.scad]
2014-10-07 tdds v.1 completed.
    [dimensions.scad, tdds.scad]
2014-10-07 cleanup of 5key_assy to get printable model again. (Shapeways started rejecting because of chock being small.)
    [5key_assy.scad, plf.scad]
2014-10-11 keycap base locking clip corrected.
    [dimensions.scad, show_tdds.scad, show_trp.scad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]
2014-10-11 4 of the 5 thumb keycaps now completed.
    [dimensions.scad, show_tcluster.scad, trp.scad]
2014-10-12 initial arrangement of thumb switches completed.
    [dimensions.scad, show_tcluster.scad, trp.scad]
2014-10-13 tweaking of proximal, inner thumb keycap.
    [dimensions.scad, show_tcluster.scad, trp.scad]
2014-10-14 Rearrange thumb cluster parts into tc.scad.
    [show_tcluster.scad, tc.scad]
2014-10-14 starting work on thumb pcb
    [kicad_fingers.sch, thumb_cluster.sch]
2014-10-20 starting work on thumb PCB.
    [dimensions.scad, show_tdds.scad, show_trp.scad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]
2014-10-21 PCB mostly routed. Shape not yet defined.
    [thumb_cluster.kicad_pcb]
2014-10-21 ground plane connected. silk cleanup still needed. soldermask slightly wrong on solder bridge. Needs corrected.
    [thumb_cluster.kicad_pcb]
2014-10-22 First pass of the Thumb Cluster PCB is complete.
    [thumb_cluster.kicad_pcb]
2014-10-23 partway done organizing model for printing.
    [dimensions.scad, print_rtcluster.scad, show_tcluster.scad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]
2014-10-26 First print of thumb cluster with this version.
    [dimensions.scad, print_rtcluster.scad, tdds.scad]
2014-10-29 added switch identifiers to switch matrix diagram.
2014-11-12 notes after working with switches.
2014-11-15 Corrected TDDS footprint, had to put it into new library in new .pretty directory format.
    [thumb_cluster.kicad_pcb]
2014-11-15 removed defective footprint from old library.
2014-11-17 correction to PNP transistor connections for easypoint switch evaluation.
    [kicad_fingers.brd, kicad_fingers.kicad_pcb, kicad_fingers.sch]

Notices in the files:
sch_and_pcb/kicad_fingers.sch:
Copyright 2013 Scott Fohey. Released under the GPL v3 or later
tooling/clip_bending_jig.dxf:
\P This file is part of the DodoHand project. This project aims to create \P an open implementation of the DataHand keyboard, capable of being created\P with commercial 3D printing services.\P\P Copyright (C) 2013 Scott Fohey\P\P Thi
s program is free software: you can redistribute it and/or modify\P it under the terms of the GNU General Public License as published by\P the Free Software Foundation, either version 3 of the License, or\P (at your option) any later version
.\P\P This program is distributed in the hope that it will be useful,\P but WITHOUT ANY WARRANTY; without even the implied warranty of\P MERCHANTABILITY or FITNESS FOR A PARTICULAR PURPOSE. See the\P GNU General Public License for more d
